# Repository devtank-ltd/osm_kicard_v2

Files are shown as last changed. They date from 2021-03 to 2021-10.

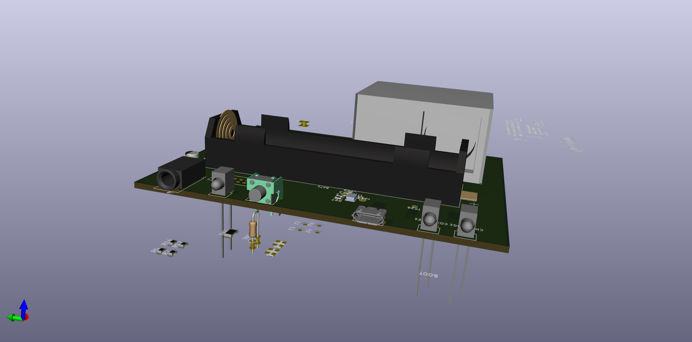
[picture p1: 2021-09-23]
kicad_osm_env01/OSM_env01.png

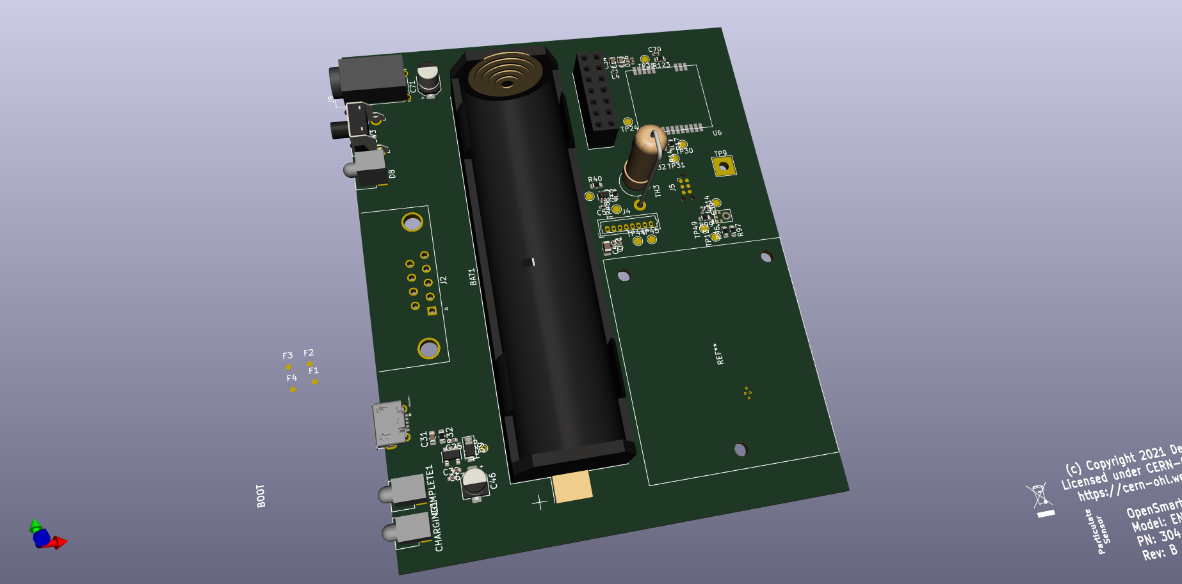
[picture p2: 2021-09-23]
kicad_osm_env01/OSM_env02.png

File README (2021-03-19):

Copyright Devtank Ltd 2021.

This documentation describes Open Hardware and is Licensed under CERN-OHL-W v2.

You may redistribute and modify this documentation under the terms of the CERN-OHL-W v2 (https://cern.ch/cern-ohl). This documentation is distributed WITHOUT ANY EXPRESS OR IMPLIED WARRANTY, INCLUDING OF MERCHANTABILITY, SATISFACTORY QUALITY AND FITNESS FOR A PARTICULAR PURPOSE. Please see the CERN-OHL-W v2 for applicable conditions

Source location: git@github.com:devtank-ltd/kicad_osm_env01.git 

As per CERN-OHL-W v2 section 4.1, should You produce hardware based on these sources, You must maintain the   Source Location visible on the external case of the product you make using this documentation.

This folder contains OSM ENV01 hardware schematics, PCB layout and BOM files. 

You will need Kicad to open hardware design files.

Open Smart Monitor and other test and measurement products can be purchased directly from Devtank Ltd.

Please contact:
Tim Telford
CTO - Devtank Ltd
+44 (0)1332 650944

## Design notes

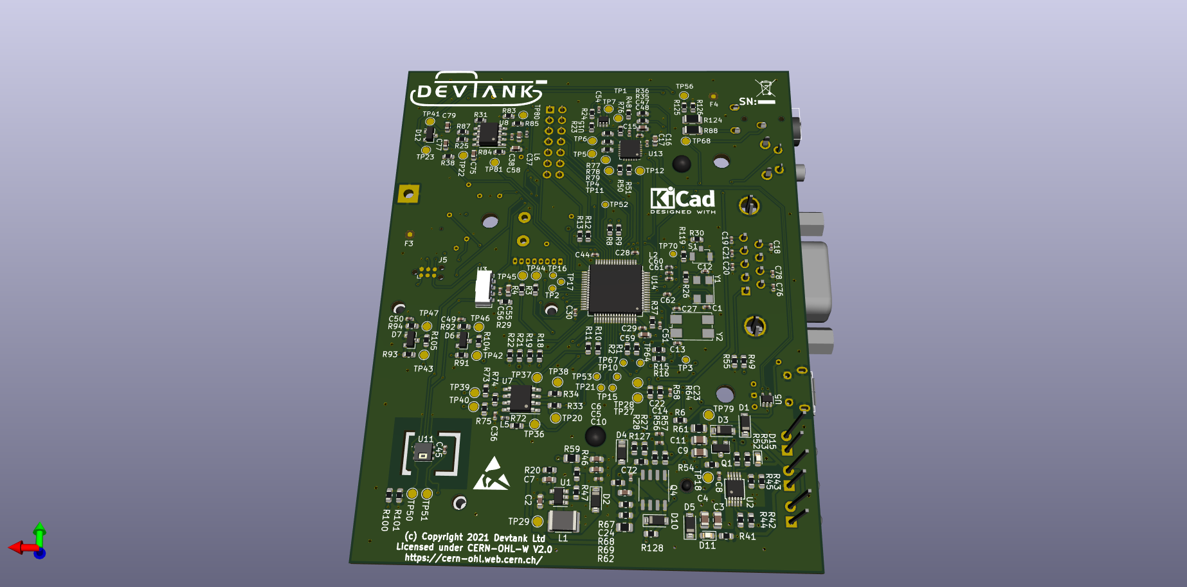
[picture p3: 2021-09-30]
kicad_osm_env01/OSM_env01__revB_img3.png

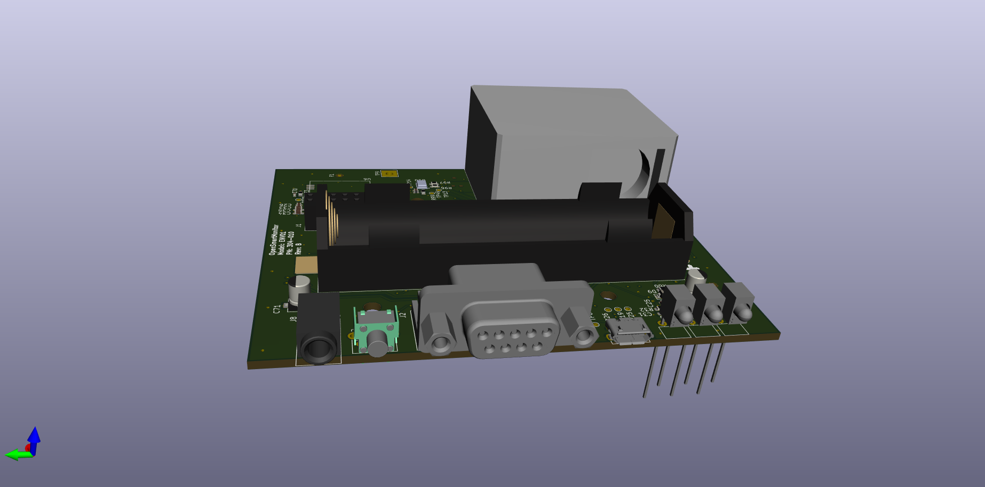
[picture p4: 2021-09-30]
kicad_osm_env01/OSM_env01__revB_img2.png

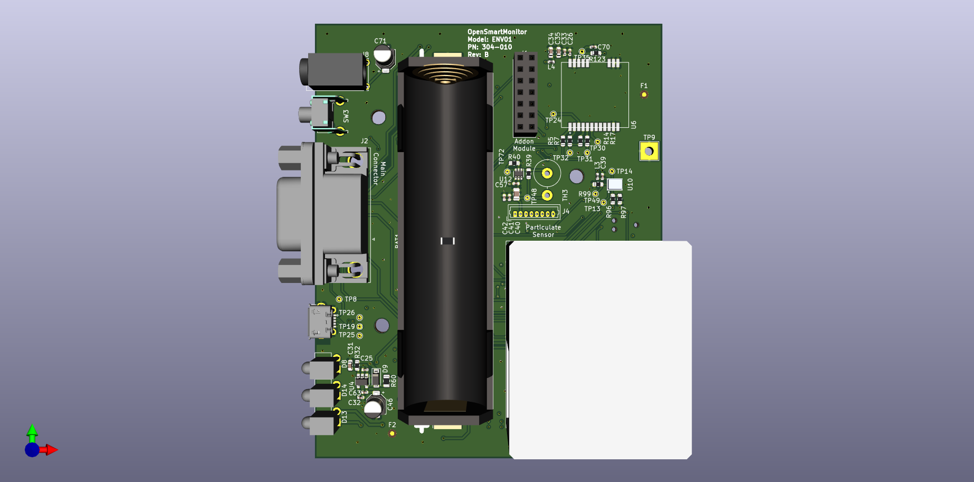
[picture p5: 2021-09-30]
kicad_osm_env01/OSM_env01__revB_img1.png

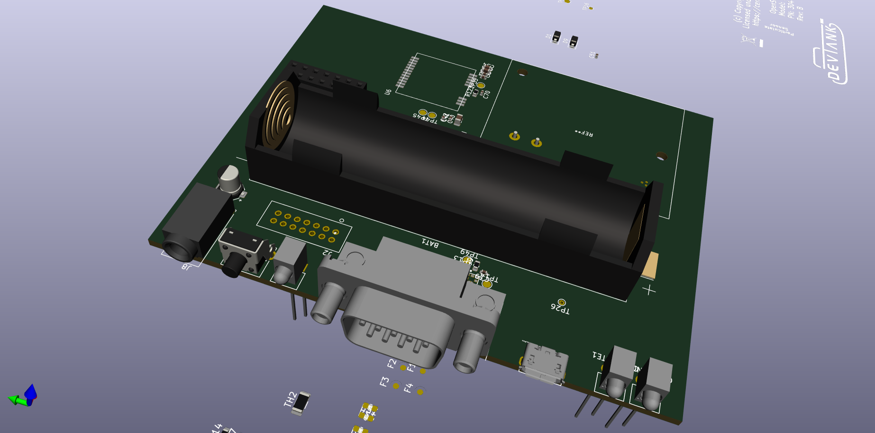
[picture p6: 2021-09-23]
kicad_osm_env01/OSM_env011.png

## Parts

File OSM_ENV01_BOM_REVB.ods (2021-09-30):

Title | Open Smart Monitor |  | Key
Revision | B |  | Orange |  | All resistors to be 1% or better (Can use your own stock)
Date | 2021-09-29 |  | Green |  | All capacitors to be rated minimum 6.3V with the exception of C71 rated 25V (Can use your own stock)
Generated | Wed 29 Sep 2021 14:41:57 BST |  | Purple |  | Use same part or similar L2-L6 to be low esr (Can use your own stock)
Company | Devtank LTD |  | Red |  | Don’t fit part
Comment 1 | Part No: 304-010 |  | Yellow |  | Free issue part by Devtank LTD
Comment 2 |  |  | Black |  | Use exact part
Comment 3
Comment 4
Total Parts | 279
Total Unique Parts | 85
Ref | Qty | Value | Footprint | Voltage | Devtank | Description | Manufacturer | Manufacturer Part Number | Supplier | Supplier Part number | Cost | Total cost | Alternative Manufacturer | Alternative manufacturer part number
BAT1 | 1 | 18650 | Devtank_PCB_lib:BatteryHolder_Keystone_1042_1x18650 |  | 750-002 | Keystone 1042 battery holder for 18650 | Keystone | 1042 | Digikey | 36-1042-ND
C1 C12 | 2 | 10pF | Capacitor_SMD:C_0402_1005Metric
C2 | 1 | 10uF | Capacitor_SMD:C_0603_1608Metric
C3 C4 C9 C11 | 4 | 47uF | Capacitor_SMD:C_0805_2012Metric
C5 C24 C34 C35 C37 | 5 | 10uF | Capacitor_SMD:C_0603_1608Metric
C6 C7 C31 C55 C58 C75 C77 C79 | 8 | DNF | Capacitor_SMD:C_0603_1608Metric
C8 C14 C25 C60 C63 | 5 | 1uF | Capacitor_SMD:C_0402_1005Metric
C10 | 1 | 4.7nF | Capacitor_SMD:C_0402_1005Metric
C13 C27 C32 C72 | 4 | DNF | Capacitor_SMD:C_0402_1005Metric
C15 C17 C22 C23 C26 C28 C29 C30 C33 C36 C38 C39 C41 C44 C45 C48 C51 C54 C56 C57 C62 C70 | 22 | 100nF | Capacitor_SMD:C_0402_1005Metric
C16 C47 C59 | 3 | 4.7uF | Capacitor_SMD:C_0603_1608Metric
C18 C19 C20 C21 C76 C78 | 6 | 100pF | Capacitor_SMD:C_0402_1005Metric
C40 | 1 | 22uF | Capacitor_SMD:C_0805_2012Metric
C42 C49 C50 C61 | 4 | 10nF | Capacitor_SMD:C_0402_1005Metric
C46 | 1 | DNF | Capacitor_SMD:CP_Elec_4x5.4
C71 | 1 | 10uF | Capacitor_SMD:CP_Elec_4x5.4 | 25V | 108-007 | 10uF 25V 5.4mmx4mm | Multicomp Pro | MCVVT025M100CA1L | Farnell | 2611368
D1 D2 D3 D4 D9 | 5 | RB160M-40TR | Diode_SMD:D_SOD-123 |  | 133-016 | Small signal schottkey diode 1A | ROHM | RB160M-40TR | Farnell | 1680023
D5 | 1 | SMFE5-0A | Diode_SMD:D_SOD-123 |  | 136-007 | 5V unidirectional TVS | Eaton | SMFE5-0A | Farnell | 3755203
D6 D7 | 2 | BAV99 | Package_TO_SOT_SMD:SOT-23 |  | 134-001 | BAV99 - Small Signal Diode, Dual Series, 75 V, 300 mA, 1.25 V, 4 ns, 4.5 | Multicomp Pro | BAV99+ | Farnell | 2675152
D8 | 1 | RED | Devtank_PCB_lib:LED_Rectangular_W4.5mm_H7.3mm_Horizontal_2.54mm_Z3.0mm |  | 110-011 | 3mm Circuit board indicator LED orange | Multicomp Pro | L514HAD | Farnell | 2627637
D10 | 1 | DNF | Diode_SMD:D_SOD-123
D11 D15 | 2 | RED | LED_SMD:LED_0603_1608Metric |  | 110-009 | Red LED | ROHM | SML-D12V8WT86C | Digikey | SML-D12V8WT86CCT-ND
D12 | 1 | DNF | Package_TO_SOT_SMD:SOT-23
D13 | 1 | GRN | Devtank_PCB_lib:LED_Rectangular_W4.5mm_H7.3mm_Horizontal_2.54mm_Z3.0mm |  | 110-012 | 3mm Circuit board indicator LED Green | Multicomp Pro | L514HGD | Farnell | 2627638
D14 | 1 | YLW | Devtank_PCB_lib:LED_Rectangular_W4.5mm_H7.3mm_Horizontal_2.54mm_Z3.0mm |  | 110-013 | 3mm Circuit board indicator LED yellow | Multicomp Pro | L514HYD | Farnell | 2627640
F1 F2 F3 F4 | 4 | Fiducial | Fiducial:Fiducial_1mm_Mask2mm
J1 | 1 | DNF | Connector_PinSocket_2.54mm:PinSocket_2x07_P2.54mm_Vertical
J2 | 1 | DB9_Female_MountingHoles | Connector_Dsub:DSUB-9_Female_Horizontal_P2.77x2.84mm_EdgePinOffset7.70mm_Housed_MountingHolesOffset9.12mm |  | 707-009 | 9 Way D Type – Female |  | DMR-09-S | Toby | DMR-09-S |  |  | Multicomp Pro | 5504F1-09S-02A-03
J3 | 1 | USB_B_Micro | Devtank_PCB_lib:MOLEX_105017-0001_USB_B |  | 703-006 | 105017-0001 - USB Connector, Micro USB Type B, USB 2.0, Receptacle, 5 Ways, Surface Mount, Right Angle | Molex | 105017-0001 | Farnell | 2293836
J4 | 1 | Conn_01x08 | Connector_Molex:Molex_PicoBlade_53047-0810_1x08_P1.25mm_Vertical |  | 714-030 | 53047-0810 - Wire-To-Board Connector, Vertical, 1.25 mm, 8 Contacts, Header, PicoBlade 53047 Series | Molex | 53047-0810 | Farnell | 1012258
J5 | 1 | DNF | Connector:Tag-Connect_TC2030-IDC-NL_2x03_P1.27mm_Vertical
J8 | 1 | STX-3000 | Devtank_PCB_lib:STX-3000 |  | 714-036 | STX3000 - Kycon 3.5mm PCB Mount, Low Profile Audio Jack | Kycon | STX-3000 | Toby Electronics | STX-3000
L1 | 1 | 10uH | Inductor_SMD:L_1812_4532Metric |  | 113-005 | LQH43PN100M26L - High Frequency Inductor, 10 µH, LQH43P_26 Series, 1.05 A, 1812 [4532 Metric], Wirewound, 0.147 ohm | muRata | LQH43PN100M26L | Digikey | 490-12780-1-ND
L2 L3 L4 L5 L6 | 5 | 2A/0.05DCR | Inductor_SMD:L_0402_1005Metric |  | 113-006 | Ferrite bead 120R 2A 0.055ohm | TDK | MPZ1005S121HT000 | Farnell | 3288291
Q1 | 1 | SI2301BDS-T1-E3 | Package_TO_SOT_SMD:SOT-23 |  | 173-009 | P-Channel MOSFET, 2.6 A, 20 V, 3-Pin SOT-23 Infineon IRLML2246TRPBF | Infineon | IRLML2246TRPBF | RS | 760-4432
Q4 | 1 | IRF7509TRPBF | Package_SO:SO-8_3.9x4.9mm_P1.27mm |  | 173-010 | Dual MOSFET, Complementary N and P Channel, 30 V, 2.7 A, 0.11 ohm, µSOIC, Surface Mount | Infineon Technologies | IRF7509TRPBF | Digikey | IRF7509TRPBFCT-ND
R1 R2 | 2 | 4.7k | Resistor_SMD:R_0603_1608Metric
R3 R4 R8 R9 R10 R11 R12 R13 R14 R17 R20 R24 R25 R27 R29 R30 R32 R33 R34 R35 R37 R38 R39 R49 R50 R51 R76 R77 R128 | 29 | 0R | Resistor_SMD:R_0603_1608Metric
R5 R7 R15 R23 R28 R31 R36 R55 R92 R94 R96 R100 R101 R119 R127 | 15 | DNF | Resistor_SMD:R_0603_1608Metric
R6 | 1 | 1.3k | Resistor_SMD:R_0603_1608Metric
R16 R48 R56 R72 R91 R93 R123 | 7 | 10k | Resistor_SMD:R_0603_1608Metric
R18 R21 R58 | 3 | 1M | Resistor_SMD:R_0603_1608Metric
R19 R22 R64 R125 R126 | 5 | 470k | Resistor_SMD:R_0603_1608Metric
R26 | 1 | 390R | Resistor_SMD:R_0603_1608Metric
R40 R57 R68 R69 R97 R99 | 6 | 100k | Resistor_SMD:R_0603_1608Metric
R41 R53 | 2 | 2.2k | Resistor_SMD:R_0603_1608Metric
R42 R44 | 2 | 1.6k | Resistor_SMD:R_0603_1608Metric
R43 R45 | 2 | 4.99k | Resistor_SMD:R_0603_1608Metric
R46 | 1 | 110k | Resistor_SMD:R_0603_1608Metric
R47 | 1 | 36k | Resistor_SMD:R_0603_1608Metric
R52 | 1 | 0R | Resistor_SMD:R_0603_1608Metric
R54 | 1 | DNF | Resistor_SMD:R_0603_1608Metric
R59 R60 R61 R62 | 4 | 0R | Resistor_SMD:R_0805_2012Metric
R67 | 1 | 300k | Resistor_SMD:R_0603_1608Metric
R73 R75 | 2 | 470R | Resistor_SMD:R_0603_1608Metric
R74 R87 | 2 | 120R | Resistor_SMD:R_0603_1608Metric
R78 R79 R84 R85 | 4 | 330R | Resistor_SMD:R_0603_1608Metric
R83 | 1 | 680R | Resistor_SMD:R_0603_1608Metric
R88 | 1 | 22R | Resistor_SMD:R_1206_3216Metric
R104 R105 | 2 | 1k | Resistor_SMD:R_0603_1608Metric
R124 | 1 | DNF | Resistor_SMD:R_1206_3216Metric
S1 | 1 | B3U-1100P | Button_Switch_SMD:SW_SPST_B3U-1100P |  | 781-003 | SMD Tactile switch | Omron | B3U-1100P | Digikey
SW3 | 1 | SW_Push | Devtank_PCB_lib:SW_Tactile_SPST_Angled_PTS645Vx58-2LFS |  | 780-002 | PTS645VH58-2LFS - Tactile Switch, PT645 Series, Side Actuated, Through Hole, Round Button, 200 gf, 50mA at 12VDC | C & K Components | PTS645VH58-2LFS | SW1021CT-ND | CKN9120-ND
TH2 | 1 | 10K | Resistor_SMD:R_1206_3216Metric |  | 155-012 | NC20K00103KBA - Thermistor, NTC, 10 kohm, NC20 Series, 3630 K, SMD, 1206 | AVX | NC20K00103KBA | Farnell | 1703890
TH3 | 1 | DNF | Resistor_THT:R_Axial_DIN0617_L17.0mm_D6.0mm_P5.08mm_Vertical
TP1 TP4 TP5 TP6 TP7 TP11 TP12 TP18 TP20 TP22 TP23 TP27 TP28 TP29 TP36 TP37 TP38 TP39 TP40 TP41 TP42 TP43 TP44 TP45 TP46 TP47 TP50 TP51 TP56 TP68 TP79 TP80 TP81 | 33 | Test_Point | TestPoint:TestPoint_Pad_D1.5mm
TP2 TP3 TP10 TP15 TP16 TP17 TP21 TP52 TP53 TP64 TP67 TP70 | 12 | Test_Point | TestPoint:TestPoint_Pad_D1.0mm
TP8 TP13 TP14 TP19 TP24 TP25 TP26 TP30 TP31 TP32 TP35 TP48 TP49 TP72 | 14 | Test_Point | TestPoint:TestPoint_THTPad_D1.0mm_Drill0.5mm
TP9 | 1 | Test_Point | TestPoint:TestPoint_THTPad_4.0x4.0mm_Drill2.0mm
U1 | 1 | MIC2250-1YD5 | Package_TO_SOT_SMD:SOT-23-5 |  | 151-008 | 2.5 MHz 2 A SMT Low EMI Boost Regulator low quiescent current 2.5-5.5v in, Output adjustable | Microchip Technology | MIC2250-1YD5-TR | Mouser | 998-MIC2250-1YD5TR
U2 | 1 | MCP73833 | Package_SO:MSOP-10_3x3mm_P0.5mm |  | 123-015 | FREE ISSUE
U3 | 1 | VEML7700-TT | Devtank_PCB_lib:VEML7700-TT |  | 155-013 | Ambient Light Sensor, VEML7700, Digital, 16 Bit, I2C, 2.5 Vdc to 3.6 Vdc | Vishay | VEML7700-TT | Digikey | 751-VEML7700-TTCT-ND
U4 | 1 | MIC5219-3.3 | Package_TO_SOT_SMD:SOT-23-5 |  | 150-009 | Low quiescent current ldo 2.5-12Vin, fixed 3.3Vout 200-500mA | Microchip Technology | MIC5219-3.3YM5-TR | Digikey | 576-1281-1-ND
U5 | 1 | SP3003-02JTG | Package_TO_SOT_SMD:SOT-353_SC-70-5 |  | 153-004 | Dual Uni-Directional TVS Diode Array | Littlefuse Inc. | SP3003-02JTG | Digikey | F3301CT-ND
U6 | 1 | RAK4270 | Devtank_PCB_lib:RAK4270_WisDuo_LPWAN_Module |  | 118-016 | FREE ISSUE
U7 | 1 | ST3485EBDR | Package_SO:SOIC-8_3.9x4.9mm_P1.27mm |  | 118-017 | Half duplex CAN Transceiver | STMicroelectronics | ST3485EBDR | RS | ST3485EBDR
U8 | 1 | DNF | Package_SO:SOIC-8_3.9x4.9mm_P1.27mm
U10 | 1 | ICS-43434 | Devtank_PCB_lib:ICS-43434 |  | 155-014 | Mic Omni-Directional -26dB 3.63V IC | TDK Invensense | ICS-43434 | Digikey | 1428-1066-1-ND
U11 | 1 | HPP845E131R5 | Devtank_PCB_lib:HPP845E131R5_temperature_humidity_sensor |  | 155-015 | HUMIDITY/TEMP SENSOR HPP845E131R5, -40 TO 125DEG C | TE Connectivity | HPP845E131R5 | RS | 187-9316
U12 | 1 | MIC94073YC6 | Package_TO_SOT_SMD:SOT-363_SC-70-6 |  | 146-002 | MIC94073YC6-TR high side load switch | Microchip Technology | MIC94073YC6-TR | Digikey | 576-3014-1-ND
U13 | 1 | CP2102N-A02-GQFN24 | Devtank_PCB_lib:CP2102_QFN-24-1EP_4x4mm_P0.5mm_EP2.6x2.6mm_ThermalVias_0.3mmdrill |  | 118-007 | FREE ISSUE
U14 | 1 | STM32L451RCTx | Package_QFP:LQFP-64_10x10mm_P0.5mm |  | 126-006 | FREE ISSUE
U15 | 1 | M74VHC1GT14DFT2G | Package_TO_SOT_SMD:SOT-353_SC-70-5 |  | 123-016 | M74VHC1GT14DFT2G Schmitt trigger inverter | On Semi | M74VHC1GT14DFT2G | Digikey | M74VHC1GT14DFT2GOSCT-ND
Y1 | 1 | 8MHZ | Crystal:Crystal_SMD_Abracon_ABM3C-4Pin_5.0x3.2mm |  | 181-013 | 8Mhz Crystal SMD, 5mm x 3.2mm, 30 ppm, 10 pF | Multicomp Pro | MCSJK-7I-8.00-10-30-60-B-30 | Farnell | 2854011
Y2 | 1 | DNF | Crystal:Crystal_SMD_7050-4Pin_7.0x5.0mm
BOM made with KICAD_BOM_WIZARD (https://github.com/HashDefineElectronics/KiCad_BOM_Wizard.git)
Generated Wed 29 Sep 2021 14:41:57 BST

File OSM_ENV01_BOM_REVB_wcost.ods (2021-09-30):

Title | Open Smart Monitor |  | Key
Revision | B |  | Orange |  | All resistors to be 1% or better (Can use your own stock)
Date | 2021-09-29 |  | Green |  | All capacitors to be rated minimum 6.3V with the exception of C71 rated 25V (Can use your own stock)
Generated | Wed 29 Sep 2021 14:41:57 BST |  | Purple |  | Use same part or similar L2-L6 to be low esr (Can use your own stock)
Company | Devtank LTD |  | Red |  | Don’t fit part
Comment 1 | Part No: 304-010 |  | Yellow |  | Free issue part by Devtank LTD
Comment 2 |  |  | Black |  | Use exact part
Comment 3
Comment 4
Total Parts | 279
Total Unique Parts | 85
Ref | Qty | Value | Footprint | Voltage | Devtank | Description | Manufacturer | Manufacturer Part Number | Supplier | Supplier Part number | Cost | Total cost | Alternative Manufacturer | Alternative manufacturer part number
BAT1 | 1 | 18650 | Devtank_PCB_lib:BatteryHolder_Keystone_1042_1x18650 |  | 750-002 | Keystone 1042 battery holder for 18650 | Keystone | 1042 | Digikey | 36-1042-ND | 2.55 | 2.55
C1 C12 | 2 | 10pF | Capacitor_SMD:C_0402_1005Metric |  |  |  |  |  |  |  |  | 0
C2 | 1 | 10uF | Capacitor_SMD:C_0603_1608Metric |  |  |  |  |  |  |  |  | 0
C3 C4 C9 C11 | 4 | 47uF | Capacitor_SMD:C_0805_2012Metric |  |  |  |  |  |  |  |  | 0
C5 C24 C34 C35 C37 | 5 | 10uF | Capacitor_SMD:C_0603_1608Metric |  |  |  |  |  |  |  |  | 0
C6 C7 C31 C55 C58 C75 C77 C79 | 8 | DNF | Capacitor_SMD:C_0603_1608Metric |  |  |  |  |  |  |  |  | 0
C8 C14 C25 C60 C63 | 5 | 1uF | Capacitor_SMD:C_0402_1005Metric |  |  |  |  |  |  |  |  | 0
C10 | 1 | 4.7nF | Capacitor_SMD:C_0402_1005Metric |  |  |  |  |  |  |  |  | 0
C13 C27 C32 C72 | 4 | DNF | Capacitor_SMD:C_0402_1005Metric |  |  |  |  |  |  |  |  | 0
C15 C17 C22 C23 C26 C28 C29 C30 C33 C36 C38 C39 C41 C44 C45 C48 C51 C54 C56 C57 C62 C70 | 22 | 100nF | Capacitor_SMD:C_0402_1005Metric |  |  |  |  |  |  |  |  | 0
C16 C47 C59 | 3 | 4.7uF | Capacitor_SMD:C_0603_1608Metric |  |  |  |  |  |  |  |  | 0
C18 C19 C20 C21 C76 C78 | 6 | 100pF | Capacitor_SMD:C_0402_1005Metric |  |  |  |  |  |  |  |  | 0
C40 | 1 | 22uF | Capacitor_SMD:C_0805_2012Metric |  |  |  |  |  |  |  |  | 0
C42 C49 C50 C61 | 4 | 10nF | Capacitor_SMD:C_0402_1005Metric |  |  |  |  |  |  |  |  | 0
C46 | 1 | DNF | Capacitor_SMD:CP_Elec_4x5.4 |  |  |  |  |  |  |  |  | 0
C71 | 1 | 10uF | Capacitor_SMD:CP_Elec_4x5.4 | 25V | 108-007 | 10uF 25V 5.4mmx4mm | Multicomp Pro | MCVVT025M100CA1L | Farnell | 2611368 | 0.0562 | 0.0562
D1 D2 D3 D4 D9 | 5 | RB160M-40TR | Diode_SMD:D_SOD-123 |  | 133-016 | Small signal schottkey diode 1A | ROHM | RB160M-40TR | Farnell | 1680023 | 0.279 | 1.395
D5 | 1 | SMFE5-0A | Diode_SMD:D_SOD-123 |  | 136-007 | 5V unidirectional TVS | Eaton | SMFE5-0A | Farnell | 3755203 | 0.141 | 0.141
D6 D7 | 2 | BAV99 | Package_TO_SOT_SMD:SOT-23 |  | 134-001 | BAV99 - Small Signal Diode, Dual Series, 75 V, 300 mA, 1.25 V, 4 ns, 4.5 | Multicomp Pro | BAV99+ | Farnell | 2675152 | 0.0581 | 0.1162
D8 | 1 | RED | Devtank_PCB_lib:LED_Rectangular_W4.5mm_H7.3mm_Horizontal_2.54mm_Z3.0mm |  | 110-011 | 3mm Circuit board indicator LED orange | Multicomp Pro | L514HAD | Farnell | 2627637 | 0.261 | 0.261
D10 | 1 | DNF | Diode_SMD:D_SOD-123 |  |  |  |  |  |  |  |  | 0
D11 D15 | 2 | RED | LED_SMD:LED_0603_1608Metric |  | 110-009 | Red LED | ROHM | SML-D12V8WT86C | Digikey | SML-D12V8WT86CCT-ND | 0.16 | 0.32
D12 | 1 | DNF | Package_TO_SOT_SMD:SOT-23 |  |  |  |  |  |  |  |  | 0
D13 | 1 | GRN | Devtank_PCB_lib:LED_Rectangular_W4.5mm_H7.3mm_Horizontal_2.54mm_Z3.0mm |  | 110-012 | 3mm Circuit board indicator LED Green | Multicomp Pro | L514HGD | Farnell | 2627638 | 0.261 | 0.261
D14 | 1 | YLW | Devtank_PCB_lib:LED_Rectangular_W4.5mm_H7.3mm_Horizontal_2.54mm_Z3.0mm |  | 110-013 | 3mm Circuit board indicator LED yellow | Multicomp Pro | L514HYD | Farnell | 2627640 | 0.261 | 0.261
F1 F2 F3 F4 | 4 | Fiducial | Fiducial:Fiducial_1mm_Mask2mm |  |  |  |  |  |  |  |  | 0
J1 | 1 | DNF | Connector_PinSocket_2.54mm:PinSocket_2x07_P2.54mm_Vertical |  |  |  |  |  |  |  |  | 0
J2 | 1 | DB9_Female_MountingHoles | Connector_Dsub:DSUB-9_Female_Horizontal_P2.77x2.84mm_EdgePinOffset7.70mm_Housed_MountingHolesOffset9.12mm |  | 707-009 | 9 Way D Type – Female | Valcon | DMR-09-S | Toby | DMR-09-S | 0.311 | 0.311 | Multicomp Pro | 5504F1-09S-02A-03
J3 | 1 | USB_B_Micro | Devtank_PCB_lib:MOLEX_105017-0001_USB_B |  | 703-006 | 105017-0001 - USB Connector, Micro USB Type B, USB 2.0, Receptacle, 5 Ways, Surface Mount, Right Angle | Molex | 105017-0001 | Farnell | 2293836 | 0.544 | 0.544
J4 | 1 | Conn_01x08 | Connector_Molex:Molex_PicoBlade_53047-0810_1x08_P1.25mm_Vertical |  | 714-030 | 53047-0810 - Wire-To-Board Connector, Vertical, 1.25 mm, 8 Contacts, Header, PicoBlade 53047 Series | Molex | 53047-0810 | Farnell | 1012258 | 0.267 | 0.267
J5 | 1 | DNF | Connector:Tag-Connect_TC2030-IDC-NL_2x03_P1.27mm_Vertical |  |  |  |  |  |  |  |  | 0
J8 | 1 | STX-3000 | Devtank_PCB_lib:STX-3000 |  | 714-036 | STX3000 - Kycon 3.5mm PCB Mount, Low Profile Audio Jack | Kycon | STX-3000 | Toby Electronics | STX-3000 | 0.38 | 0.38
L1 | 1 | 10uH | Inductor_SMD:L_1812_4532Metric |  | 113-005 | LQH43PN100M26L - High Frequency Inductor, 10 µH, LQH43P_26 Series, 1.05 A, 1812 [4532 Metric], Wirewound, 0.147 ohm | muRata | LQH43PN100M26L | Digikey | 490-12780-1-ND | 0.19 | 0.19
L2 L3 L4 L5 L6 | 5 | 2A/0.05DCR | Inductor_SMD:L_0402_1005Metric |  | 113-006 | Ferrite bead 120R 2A 0.055ohm | TDK | MPZ1005S121HT000 | Farnell | 3288291 | 0.0694 | 0.347
Q1 | 1 | SI2301BDS-T1-E3 | Package_TO_SOT_SMD:SOT-23 |  | 173-009 | P-Channel MOSFET, 2.6 A, 20 V, 3-Pin SOT-23 Infineon IRLML2246TRPBF | Infineon | IRLML2246TRPBF | RS | 760-4432 | 0.344 | 0.344
Q4 | 1 | IRF7509TRPBF | Package_SO:SO-8_3.9x4.9mm_P1.27mm |  | 173-010 | Dual MOSFET, Complementary N and P Channel, 30 V, 2.7 A, 0.11 ohm, µSOIC, Surface Mount | Infineon Technologies | IRF7509TRPBF | Digikey | IRF7509TRPBFCT-ND | 0.552 | 0.552
R1 R2 | 2 | 4.7k | Resistor_SMD:R_0603_1608Metric |  |  |  |  |  |  |  |  | 0
R3 R4 R8 R9 R10 R11 R12 R13 R14 R17 R20 R24 R25 R27 R29 R30 R32 R33 R34 R35 R37 R38 R39 R49 R50 R51 R76 R77 R128 | 29 | 0R | Resistor_SMD:R_0603_1608Metric |  |  |  |  |  |  |  |  | 0
R5 R7 R15 R23 R28 R31 R36 R55 R92 R94 R96 R100 R101 R119 R127 | 15 | DNF | Resistor_SMD:R_0603_1608Metric |  |  |  |  |  |  |  |  | 0
R6 | 1 | 1.3k | Resistor_SMD:R_0603_1608Metric |  |  |  |  |  |  |  |  | 0
R16 R48 R56 R72 R91 R93 R123 | 7 | 10k | Resistor_SMD:R_0603_1608Metric |  |  |  |  |  |  |  |  | 0
R18 R21 R58 | 3 | 1M | Resistor_SMD:R_0603_1608Metric |  |  |  |  |  |  |  |  | 0
R19 R22 R64 R125 R126 | 5 | 470k | Resistor_SMD:R_0603_1608Metric |  |  |  |  |  |  |  |  | 0
R26 | 1 | 390R | Resistor_SMD:R_0603_1608Metric |  |  |  |  |  |  |  |  | 0
R40 R57 R68 R69 R97 R99 | 6 | 100k | Resistor_SMD:R_0603_1608Metric |  |  |  |  |  |  |  |  | 0
R41 R53 | 2 | 2.2k | Resistor_SMD:R_0603_1608Metric |  |  |  |  |  |  |  |  | 0
R42 R44 | 2 | 1.6k | Resistor_SMD:R_0603_1608Metric |  |  |  |  |  |  |  |  | 0
R43 R45 | 2 | 4.99k | Resistor_SMD:R_0603_1608Metric |  |  |  |  |  |  |  |  | 0
R46 | 1 | 110k | Resistor_SMD:R_0603_1608Metric |  |  |  |  |  |  |  |  | 0
R47 | 1 | 36k | Resistor_SMD:R_0603_1608Metric |  |  |  |  |  |  |  |  | 0
R52 | 1 | 0R | Resistor_SMD:R_0603_1608Metric |  |  |  |  |  |  |  |  | 0
R54 | 1 | DNF | Resistor_SMD:R_0603_1608Metric |  |  |  |  |  |  |  |  | 0
R59 R60 R61 R62 | 4 | 0R | Resistor_SMD:R_0805_2012Metric |  |  |  |  |  |  |  |  | 0
R67 | 1 | 300k | Resistor_SMD:R_0603_1608Metric |  |  |  |  |  |  |  |  | 0
R73 R75 | 2 | 470R | Resistor_SMD:R_0603_1608Metric |  |  |  |  |  |  |  |  | 0
R74 R87 | 2 | 120R | Resistor_SMD:R_0603_1608Metric |  |  |  |  |  |  |  |  | 0
R78 R79 R84 R85 | 4 | 330R | Resistor_SMD:R_0603_1608Metric |  |  |  |  |  |  |  |  | 0
R83 | 1 | 680R | Resistor_SMD:R_0603_1608Metric |  |  |  |  |  |  |  |  | 0
R88 | 1 | 22R | Resistor_SMD:R_1206_3216Metric |  |  |  |  |  |  |  |  | 0
R104 R105 | 2 | 1k | Resistor_SMD:R_0603_1608Metric |  |  |  |  |  |  |  |  | 0
R124 | 1 | DNF | Resistor_SMD:R_1206_3216Metric |  |  |  |  |  |  |  |  | 0
S1 | 1 | B3U-1100P | Button_Switch_SMD:SW_SPST_B3U-1100P |  | 781-003 | SMD Tactile switch SPST-NO 50mA 12V | Omron | B3U-1100P | Digikey |  | 0.63 | 0.63
SW3 | 1 | SW_Push | Devtank_PCB_lib:SW_Tactile_SPST_Angled_PTS645Vx58-2LFS |  | 780-002 | PTS645VH58-2LFS - Tactile Switch, PT645 Series, Side Actuated, Through Hole, Round Button, 200 gf, 50mA at 12VDC | C & K Components | PTS645VH58-2LFS | SW1021CT-ND | CKN9120-ND | 0.18 | 0.18
TH2 | 1 | 10K | Resistor_SMD:R_1206_3216Metric |  | 155-012 | NC20K00103KBA - Thermistor, NTC, 10 kohm, NC20 Series, 3630 K, SMD, 1206 | AVX | NC20K00103KBA | Farnell | 1703890 | 0.311 | 0.311
TH3 | 1 | DNF | Resistor_THT:R_Axial_DIN0617_L17.0mm_D6.0mm_P5.08mm_Vertical |  |  |  |  |  |  |  |  | 0
TP1 TP4 TP5 TP6 TP7 TP11 TP12 TP18 TP20 TP22 TP23 TP27 TP28 TP29 TP36 TP37 TP38 TP39 TP40 TP41 TP42 TP43 TP44 TP45 TP46 TP47 TP50 TP51 TP56 TP68 TP79 TP80 TP81 | 33 | Test_Point | TestPoint:TestPoint_Pad_D1.5mm |  |  |  |  |  |  |  |  | 0
TP2 TP3 TP10 TP15 TP16 TP17 TP21 TP52 TP53 TP64 TP67 TP70 | 12 | Test_Point | TestPoint:TestPoint_Pad_D1.0mm |  |  |  |  |  |  |  |  | 0
TP8 TP13 TP14 TP19 TP24 TP25 TP26 TP30 TP31 TP32 TP35 TP48 TP49 TP72 | 14 | Test_Point | TestPoint:TestPoint_THTPad_D1.0mm_Drill0.5mm |  |  |  |  |  |  |  |  | 0
TP9 | 1 | Test_Point | TestPoint:TestPoint_THTPad_4.0x4.0mm_Drill2.0mm |  |  |  |  |  |  |  |  | 0
U1 | 1 | MIC2250-1YD5 | Package_TO_SOT_SMD:SOT-23-5 |  | 151-008 | 2.5 MHz 2 A SMT Low EMI Boost Regulator low quiescent current 2.5-5.5v in, Output adjustable | Microchip Technology | MIC2250-1YD5-TR | Mouser | 998-MIC2250-1YD5TR | 0.526 | 0.526
U2 | 1 | MCP73833 | Package_SO:MSOP-10_3x3mm_P0.5mm |  | 123-015 | Stand-Alone Linear Battery Charge Controller | Microchip Technology | MCP73833T-AMI/UN | Digikey998-MIC2250-1YD5TR | MCP73833T-AMI/UNCT-ND | 0.64 | 0.64
U3 | 1 | VEML7700-TT | Devtank_PCB_lib:VEML7700-TT |  | 155-013 | Ambient Light Sensor, VEML7700, Digital, 16 Bit, I2C, 2.5 Vdc to 3.6 Vdc | Vishay | VEML7700-TT | Digikey | 751-VEML7700-TTCT-ND | 0.9 | 0.9
U4 | 1 | MIC5219-3.3 | Package_TO_SOT_SMD:SOT-23-5 |  | 150-009 | Low quiescent current ldo 2.5-12Vin, fixed 3.3Vout 200mA, 500mA peak current | Microchip Technology | MIC5219-3.3YM5-TR | Digikey | 576-1281-1-ND | 0.664 | 0.664
U5 | 1 | SP3003-02JTG | Package_TO_SOT_SMD:SOT-353_SC-70-5 |  | 153-004 | Dual Uni-Directional TVS Diode Array | Littlefuse Inc. | SP3003-02JTG | Digikey | F3301CT-ND | 0.615 | 0.615
U6 | 1 | RAK4270 | Devtank_PCB_lib:RAK4270_WisDuo_LPWAN_Module |  | 118-016 | RAK4270 WisDuo LPWAN Module with IPEX EU868 | rakwireless | RAK4270 WisDuo LPWAN Module with IPEX EU868 | rakwireless | RAK4270 WisDuo LPWAN Module with IPEX EU868 | 5.2 | 5.2
U7 | 1 | ST3485EBDR | Package_SO:SOIC-8_3.9x4.9mm_P1.27mm |  | 118-017 | Half duplex CAN Transceiver | STMicroelectronics | ST3485EBDR | RS | ST3485EBDR | 1.72 | 1.72
U8 | 1 | DNF | Package_SO:SOIC-8_3.9x4.9mm_P1.27mm |  |  |  |  |  |  |  |  | 0
U10 | 1 | ICS-43434 | Devtank_PCB_lib:ICS-43434 |  | 155-014 | Mic Omni-Directional -26dB 3.63V IC | TDK Invensense | ICS-43434 | Digikey | 1428-1066-1-ND | 1.369 | 1.369
U11 | 1 | HPP845E131R5 | Devtank_PCB_lib:HPP845E131R5_temperature_humidity_sensor |  | 155-015 | HUMIDITY/TEMP SENSOR HPP845E131R5, -40 TO 125DEG C | TE Connectivity | HPP845E131R5 | RS | 187-9316 | 1.534 | 1.534
U12 | 1 | MIC94073YC6 | Package_TO_SOT_SMD:SOT-363_SC-70-6 |  | 146-002 | MIC94073YC6-TR high side load switch | Microchip Technology | MIC94073YC6-TR | Digikey | 576-3014-1-ND | 0.339 | 0.339
U13 | 1 | CP2102N-A02-GQFN24 | Devtank_PCB_lib:CP2102_QFN-24-1EP_4x4mm_P0.5mm_EP2.6x2.6mm_ThermalVias_0.3mmdrill |  | 118-007 | Silicon Labs CP2102N-A02-GQFN24, USB Controller, 12Mbps, USB 2.0, 3 to 3.6 V, 24-Pin QFN | Silicon Labs | CP2102N-A02-GQFN24 | Mouser | 634-CP2102NA02GQFN24 | 1.46 | 1.46
U14 | 1 | STM32L451RCTx | Package_QFP:LQFP-64_10x10mm_P0.5mm |  | 126-006 | STM32L451RCT6 Microcontroler | STMicroelectronics | STM32L451RCT6 | Digikey | 497-17975-ND | 4.489 | 4.489
U15 | 1 | M74VHC1GT14DFT2G | Package_TO_SOT_SMD:SOT-353_SC-70-5 |  | 123-016 | M74VHC1GT14DFT2G Schmitt trigger inverter | On Semi | M74VHC1GT14DFT2G | Digikey | M74VHC1GT14DFT2GOSCT-ND | 0.138 | 0.138
Y1 | 1 | 8MHZ | Crystal:Crystal_SMD_Abracon_ABM3C-4Pin_5.0x3.2mm |  | 181-013 | 8Mhz Crystal SMD, 5mm x 3.2mm, 30 ppm, 10 pF | Multicomp Pro | MCSJK-7I-8.00-10-30-60-B-30 | Farnell | 2854011 | 0.286 | 0.286
Y2 | 1 | DNF | Crystal:Crystal_SMD_7050-4Pin_7.0x5.0mm |  |  |  |  |  |  |  |  | 0
 |  |  |  |  |  |  |  |  |  |  |  | 29.2974
BOM made with KICAD_BOM_WIZARD (https://github.com/HashDefineElectronics/KiCad_BOM_Wizard.git)
Generated Wed 29 Sep 2021 14:41:57 BST

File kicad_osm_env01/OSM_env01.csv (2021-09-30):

Title | Open Smart Monitor
Revision | B
Date | 2021-09-29
Generated | Wed 29 Sep 2021 14:41:57 BST
Company | Devtank LTD
Comment 1 | Part No: 304-010
Comment 2
Comment 3
Comment 4
Total Parts | 279
Total Unique Parts | 85
Ref | Qty | Value | Footprint | Datasheet | Current | Devtank | Field4 | Field5 | Field6 | Field7 | Field8 | Fieldname 1 | Fieldname2 | Fieldname3 | MANUFACTURER | Package | Voltage
BAT1 | 1 | 18650 | Devtank_PCB_lib:BatteryHolder_Keystone_1042_1x18650 |  |  |  |  |  |  |  |  | Value 1 | Value2 | Value3
C1 C12 | 2 | 18pF | Capacitor_SMD:C_0402_1005Metric
C2 | 1 | 10uF | Capacitor_SMD:C_0603_1608Metric |  |  |  |  |  |  |  |  |  |  |  |  |  | 10V
C3 C4 C9 C11 | 4 | 47uF | Capacitor_SMD:C_0805_2012Metric |  |  |  |  |  |  |  |  |  |  |  |  | 0805
C5 C24 C34 C35 C37 | 5 | 10uF | Capacitor_SMD:C_0603_1608Metric
C6 C7 C31 C55 C58 C75 C77 C79 | 8 | DNF | Capacitor_SMD:C_0603_1608Metric
C8 C14 C25 C60 C63 | 5 | 1uF | Capacitor_SMD:C_0402_1005Metric
C10 | 1 | 4.7nF | Capacitor_SMD:C_0402_1005Metric
C13 C27 C32 C72 | 4 | DNF | Capacitor_SMD:C_0402_1005Metric
C15 C17 C22 C23 C26 C28 C29 C30 C33 C36 C38 C39 C41 C44 C45 C48 C51 C54 C56 C57 C62 C70 | 22 | 100nF | Capacitor_SMD:C_0402_1005Metric
C16 C47 C59 | 3 | 4.7uF | Capacitor_SMD:C_0603_1608Metric
C18 C19 C20 C21 C76 C78 | 6 | 100pF | Capacitor_SMD:C_0402_1005Metric
C40 | 1 | 22uF | Capacitor_SMD:C_0805_2012Metric
C42 C49 C50 C61 | 4 | 10nF | Capacitor_SMD:C_0402_1005Metric
C46 | 1 | DNF | Capacitor_SMD:CP_Elec_4x5.4
C71 | 1 | 10uF | Capacitor_SMD:CP_Elec_4x5.4
D1 D2 D3 D4 D9 | 5 | RB160M-40TR | Diode_SMD:D_SOD-123
D5 | 1 | SMFE5-0A | Diode_SMD:D_SOD-123 | https://en.wikipedia.org/wiki/Transient-voltage-suppression_diode
D6 D7 | 2 | BAV99 | Package_TO_SOT_SMD:SOT-23 | www.nxp.com/documents/data_sheet/BAV99_SER.pdf |  | 134-001
D8 | 1 | RED | Devtank_PCB_lib:LED_Rectangular_W4.5mm_H7.3mm_Horizontal_2.54mm_Z3.0mm | ~
D10 | 1 | DNF | Diode_SMD:D_SOD-123
D11 D15 | 2 | RED | LED_SMD:LED_0603_1608Metric |  |  |  |  |  |  |  |  | Value 1 | Value2 | Value3
D12 | 1 | ESDCAN04-2BLY | Package_TO_SOT_SMD:SOT-23 | https://en.wikipedia.org/wiki/Transient-voltage-suppression_diode
D13 | 1 | GRN | Devtank_PCB_lib:LED_Rectangular_W4.5mm_H7.3mm_Horizontal_2.54mm_Z3.0mm |  |  |  |  |  |  |  |  | Value 1 | Value2 | Value3
D14 | 1 | YLW | Devtank_PCB_lib:LED_Rectangular_W4.5mm_H7.3mm_Horizontal_2.54mm_Z3.0mm |  |  |  |  |  |  |  |  | Value 1 | Value2 | Value3
F1 F2 F3 F4 | 4 | Fiducial | Fiducial:Fiducial_1mm_Mask2mm
J1 | 1 | Conn_02x07_Counter_Clockwise | Connector_PinSocket_2.54mm:PinSocket_2x07_P2.54mm_Vertical | ~
J2 | 1 | DB9_Female_MountingHoles | Connector_Dsub:DSUB-9_Female_Horizontal_P2.77x2.84mm_EdgePinOffset7.70mm_Housed_MountingHolesOffset9.12mm
J3 | 1 | USB_B_Micro | Devtank_PCB_lib:MOLEX_105017-0001_USB_B | ~
J4 | 1 | Conn_01x08 | Connector_Molex:Molex_PicoBlade_53047-0810_1x08_P1.25mm_Vertical | ~
J5 | 1 | Conn_02x03_Odd_Even | Connector:Tag-Connect_TC2030-IDC-NL_2x03_P1.27mm_Vertical | ~
J8 | 1 | STX-3000 | Devtank_PCB_lib:STX-3000
L1 | 1 | 10uH | Inductor_SMD:L_1812_4532Metric |  | 1A
L2 L3 L4 L5 L6 | 5 | 2A/0.05DCR | Inductor_SMD:L_0402_1005Metric
Q1 | 1 | SI2301BDS-T1-E3 | Package_TO_SOT_SMD:SOT-23 | https://www.fairchildsemi.com/datasheets/BS/BSS138.pdf
Q4 | 1 | IRF7509TRPBF | Package_SO:SO-8_3.9x4.9mm_P1.27mm | Mosfet Array N and P-Channel 30V 2W Surface Mount 8-SO |  |  | Infineon Technologies | Unavailable | SO-8 Infineon | None | IRF7319TRPBF
R1 R2 | 2 | 4.7k | Resistor_SMD:R_0603_1608Metric
R3 R4 R8 R9 R10 R11 R12 R13 R14 R17 R20 R24 R25 R27 R29 R30 R32 R33 R34 R35 R37 R38 R39 R49 R50 R51 R76 R77 R128 | 29 | 0R | Resistor_SMD:R_0603_1608Metric
R5 R7 R15 R23 R28 R31 R36 R55 R92 R94 R96 R100 R101 R119 R127 | 15 | DNF | Resistor_SMD:R_0603_1608Metric
R6 | 1 | 1.3k | Resistor_SMD:R_0603_1608Metric
R16 R48 R56 R72 R91 R93 R123 | 7 | 10k | Resistor_SMD:R_0603_1608Metric
R18 R21 R58 | 3 | 1M | Resistor_SMD:R_0603_1608Metric
R19 R22 R64 R125 R126 | 5 | 470k | Resistor_SMD:R_0603_1608Metric
R26 | 1 | 390R | Resistor_SMD:R_0603_1608Metric
R40 R57 R68 R69 R97 R99 | 6 | 100k | Resistor_SMD:R_0603_1608Metric
R41 R53 | 2 | 2.2k | Resistor_SMD:R_0603_1608Metric |  |  |  |  |  |  |  |  | Value 1 | Value2 | Value3
R42 R44 | 2 | 1.6k | Resistor_SMD:R_0603_1608Metric |  |  |  |  |  |  |  |  | Value 1 | Value2 | Value3
R43 R45 | 2 | 4.99k | Resistor_SMD:R_0603_1608Metric |  |  |  |  |  |  |  |  | Value 1 | Value2 | Value3
R46 | 1 | 110k | Resistor_SMD:R_0603_1608Metric
R47 | 1 | 36k | Resistor_SMD:R_0603_1608Metric
R52 | 1 | 0R | Resistor_SMD:R_0603_1608Metric |  |  |  |  |  |  |  |  | Value 1 | Value2 | Value3
R54 | 1 | DNF | Resistor_SMD:R_0603_1608Metric |  |  |  |  |  |  |  |  | Value 1 | Value2 | Value3
R59 R60 R61 R62 | 4 | 0R | Resistor_SMD:R_0805_2012Metric
R67 | 1 | 300k | Resistor_SMD:R_0603_1608Metric
R73 R75 | 2 | 470R | Resistor_SMD:R_0603_1608Metric
R74 R87 | 2 | 120R | Resistor_SMD:R_0603_1608Metric
R78 R79 R84 R85 | 4 | 330R | Resistor_SMD:R_0603_1608Metric
R83 | 1 | 680R | Resistor_SMD:R_0603_1608Metric
R88 | 1 | 22R | Resistor_SMD:R_1206_3216Metric
R104 R105 | 2 | 1k | Resistor_SMD:R_0603_1608Metric
R124 | 1 | DNF | Resistor_SMD:R_1206_3216Metric
S1 | 1 | B3U-1100P | Button_Switch_SMD:SW_SPST_B3U-1100P |  |  |  |  |  |  |  |  |  |  |  | Omron
SW3 | 1 | SW_Push | Devtank_PCB_lib:SW_Tactile_SPST_Angled_PTS645Vx58-2LFS
TH2 | 1 | 10K | Resistor_SMD:R_1206_3216Metric
TH3 | 1 | DNF | Resistor_THT:R_Axial_DIN0617_L17.0mm_D6.0mm_P5.08mm_Vertical
TP1 TP4 TP5 TP6 TP7 TP11 TP12 TP18 TP20 TP22 TP23 TP27 TP28 TP29 TP36 TP37 TP38 TP39 TP40 TP41 TP42 TP43 TP44 TP45 TP46 TP47 TP50 TP51 TP56 TP68 TP79 TP80 TP81 | 33 | Test_Point | TestPoint:TestPoint_Pad_D1.5mm | ~
TP2 TP3 TP10 TP15 TP16 TP17 TP21 TP52 TP53 TP64 TP67 TP70 | 12 | Test_Point | TestPoint:TestPoint_Pad_D1.0mm | ~
TP8 TP13 TP14 TP19 TP24 TP25 TP26 TP30 TP31 TP32 TP35 TP48 TP49 TP72 | 14 | Test_Point | TestPoint:TestPoint_THTPad_D1.0mm_Drill0.5mm | ~
TP9 | 1 | Test_Point | TestPoint:TestPoint_THTPad_4.0x4.0mm_Drill2.0mm | ~
U1 | 1 | MIC2250-1YD5 | Package_TO_SOT_SMD:SOT-23-5 | http://ww1.microchip.com/downloads/en/DeviceDoc/mic2177.pdf
U2 | 1 | MCP73833 | Package_SO:MSOP-10_3x3mm_P0.5mm |  |  |  |  |  |  |  |  | Value 1 | Value2 | Value3
U3 | 1 | VEML7700-TT | Devtank_PCB_lib:VEML7700-TT
U4 | 1 | MIC5219-3.3 | Package_TO_SOT_SMD:SOT-23-5 | http://ww1.microchip.com/downloads/en/devicedoc/mic5219.pdf
U5 | 1 | SP3003-02JTG | Package_TO_SOT_SMD:SOT-353_SC-70-5 | DOCUMENTATION
U6 | 1 | RAK4270 | Devtank_PCB_lib:RAK4270_WisDuo_LPWAN_Module
U7 | 1 | ST3485EBDR | Package_SO:SOIC-8_3.9x4.9mm_P1.27mm | http://www.intersil.com/content/dam/Intersil/documents/isl8/isl83483-85-88-90-91.pdf
U8 | 1 | SN65HVD230 | Package_SO:SOIC-8_3.9x4.9mm_P1.27mm | http://www.ti.com/lit/ds/symlink/sn65hvd230.pdf
U10 | 1 | ICS-43434 | Devtank_PCB_lib:ICS-43434
U11 | 1 | HPP845E131R5 | Devtank_PCB_lib:HPP845E131R5_temperature_humidity_sensor
U12 | 1 | MIC94073YC6 | Package_TO_SOT_SMD:SOT-363_SC-70-6
U13 | 1 | CP2102N-A01-GQFN24 | Devtank_PCB_lib:CP2102_QFN-24-1EP_4x4mm_P0.5mm_EP2.6x2.6mm_ThermalVias_0.3mmdrill | http://www.silabs.com/support%20documents/technicaldocs/cp2102n-datasheet.pdf |  | 118-007
U14 | 1 | STM32L451RCTx | Package_QFP:LQFP-64_10x10mm_P0.5mm | http://www.st.com/st-web-ui/static/active/en/resource/technical/document/datasheet/DM00108832.pdf
U15 | 1 | M74VHC1GT14DFT2G | Package_TO_SOT_SMD:SOT-353_SC-70-5
Y1 | 1 | 8MHZ | Crystal:Crystal_SMD_Abracon_ABM3C-4Pin_5.0x3.2mm
Y2 | 1 | DNF | Crystal:Crystal_SMD_7050-4Pin_7.0x5.0mm
BOM made with KICAD_BOM_WIZARD (https://github.com/HashDefineElectronics/KiCad_BOM_Wizard.git)
Generated Wed 29 Sep 2021 14:41:57 BST

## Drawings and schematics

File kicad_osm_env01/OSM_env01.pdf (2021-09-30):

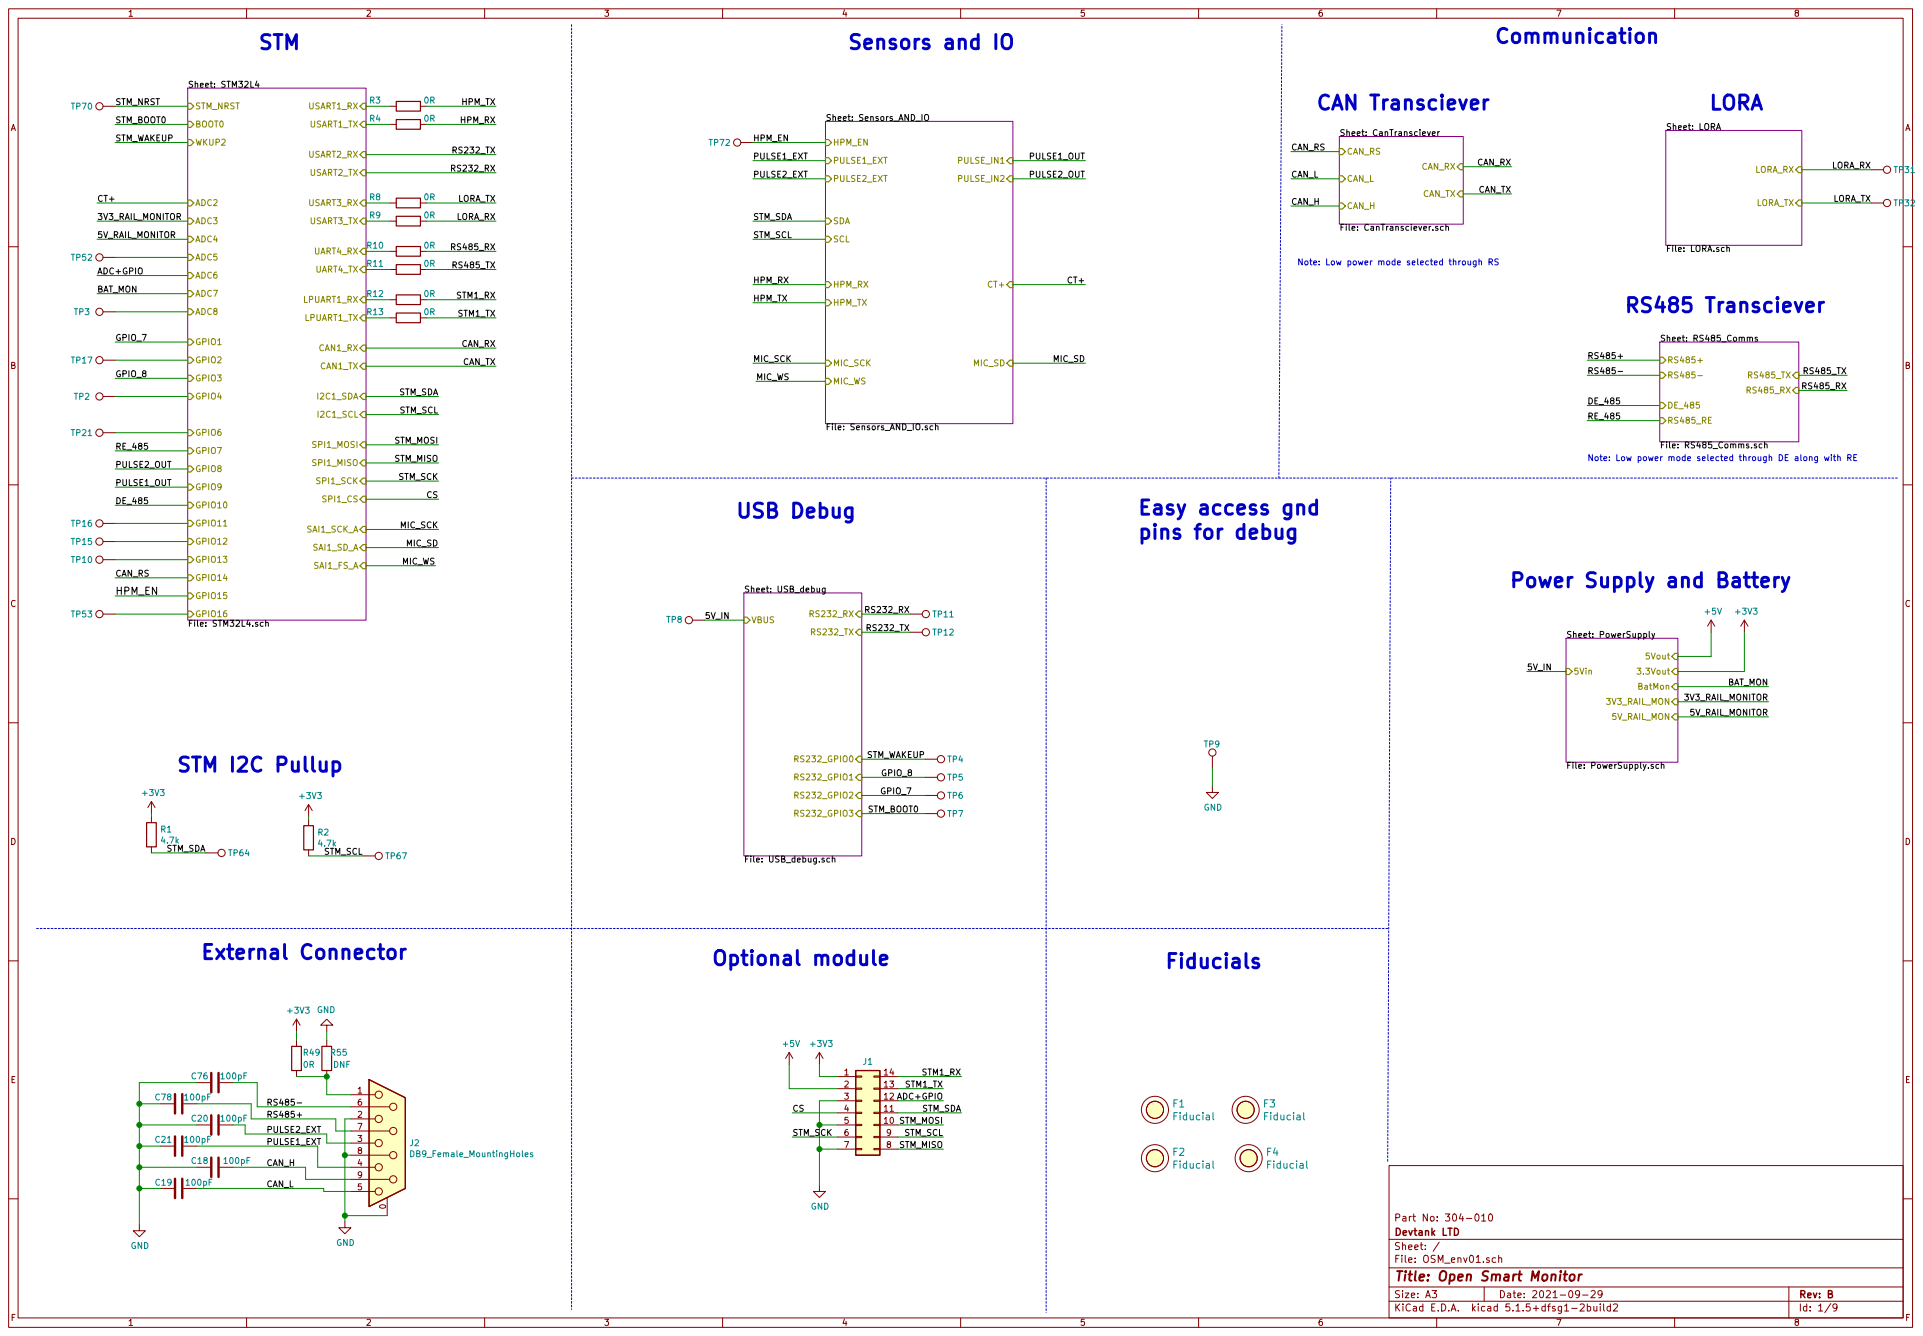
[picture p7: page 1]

Sheet: CanTransciever File: CanTransciever.sch CAN_RX CAN_TX CAN_L CAN_H
CAN_RS

Note: Low power mode selected through RS

Note: Low power mode selected through DE along with RE

Power Supply and Battery

Part No: 304-010
File: OSM_env01.sch Sheet: / Devtank LTD

Id: 1/9 Title: Open Smart Monitor

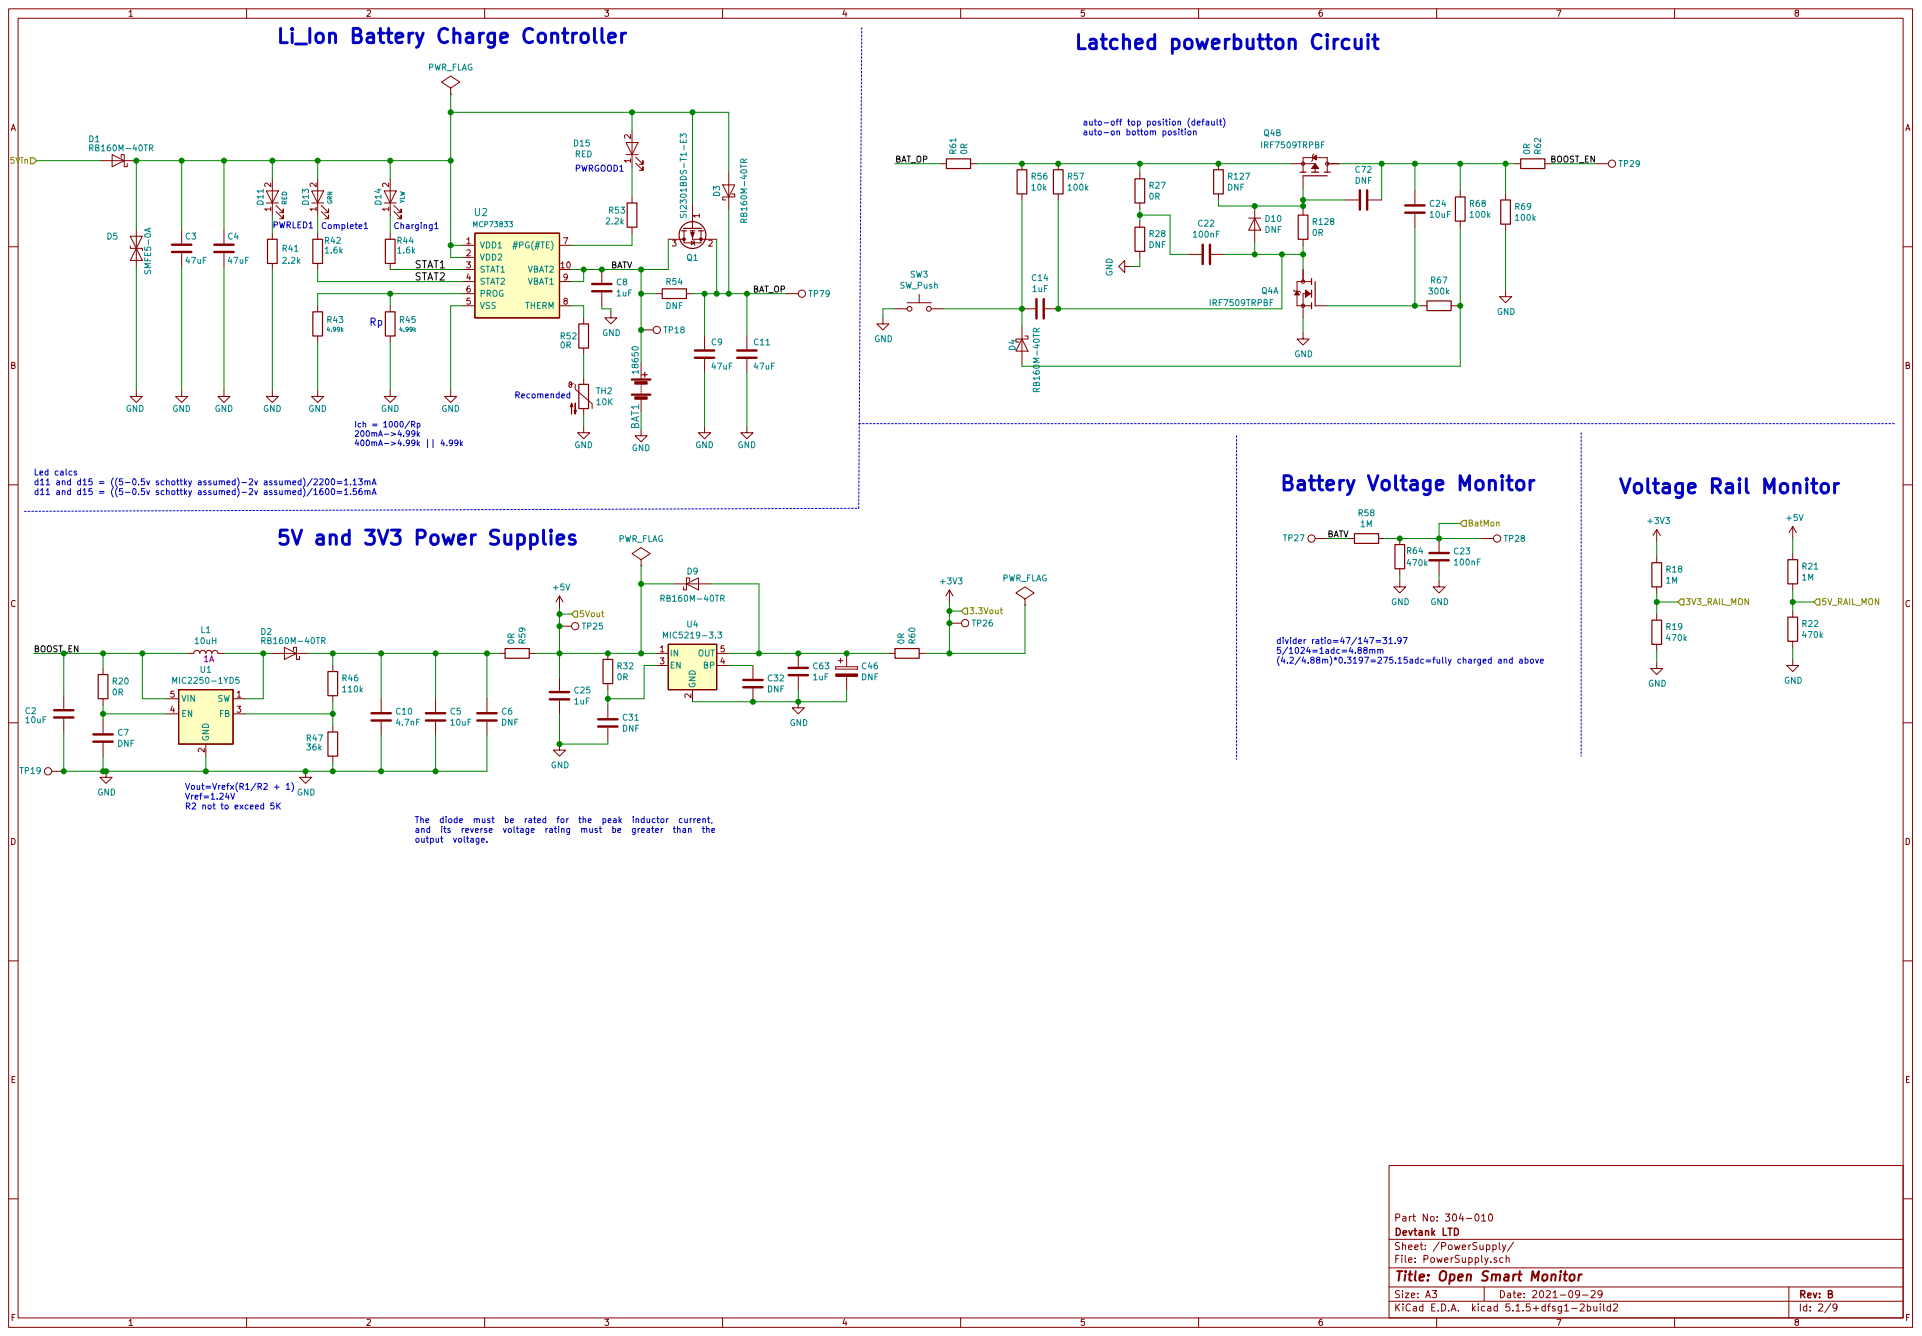
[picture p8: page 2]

auto-on bottom position
IRF7509TRPBF Q4A

2 FB 3 EN 4 VIN 5 U1 MIC2250-1YD5 GND GND

Led calcs d11 and d15 = ((5-0.5v schottky assumed)-2v assumed)/2200=1.13mA

BATV 5V and 3V3 Power Supplies

divider ratio=47/147=31.97
5/1024=1adc=4.88mm
(4.2/4.88m)*0.3197=275.15adc=fully charged and above

The diode must be rated for the peak inductor current,
and its reverse voltage rating must be greater than the
output voltage.

Part No: 304-010
Sheet: /PowerSupply/ Devtank LTD

File: PowerSupply.sch
Id: 2/9 Title: Open Smart Monitor

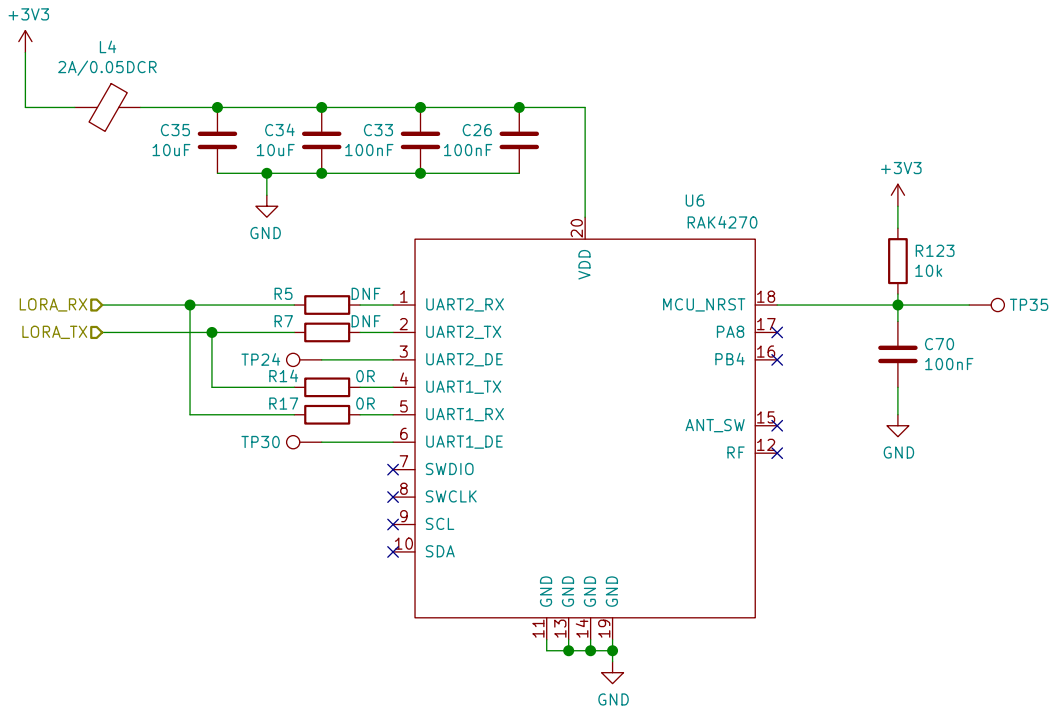
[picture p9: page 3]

Part No: 304-010
Id: 3/9 Title: Open Smart Monitor File: LORA.sch Sheet: /LORA/ Devtank LTD

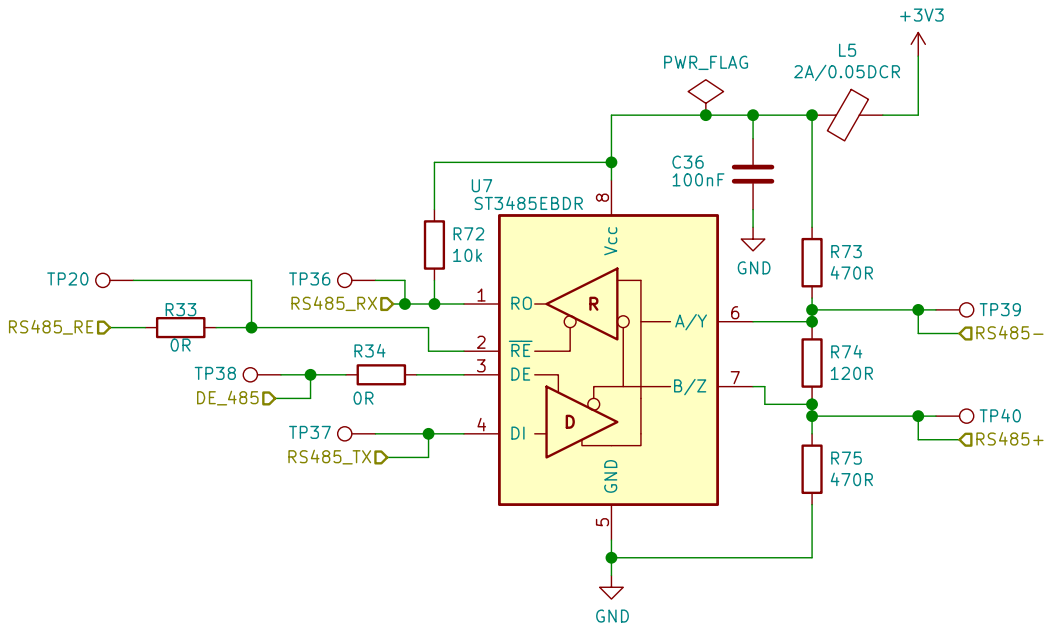
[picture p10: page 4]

File: RS485_Comms.sch
Id: 4/9 Title: Open Smart Monitor

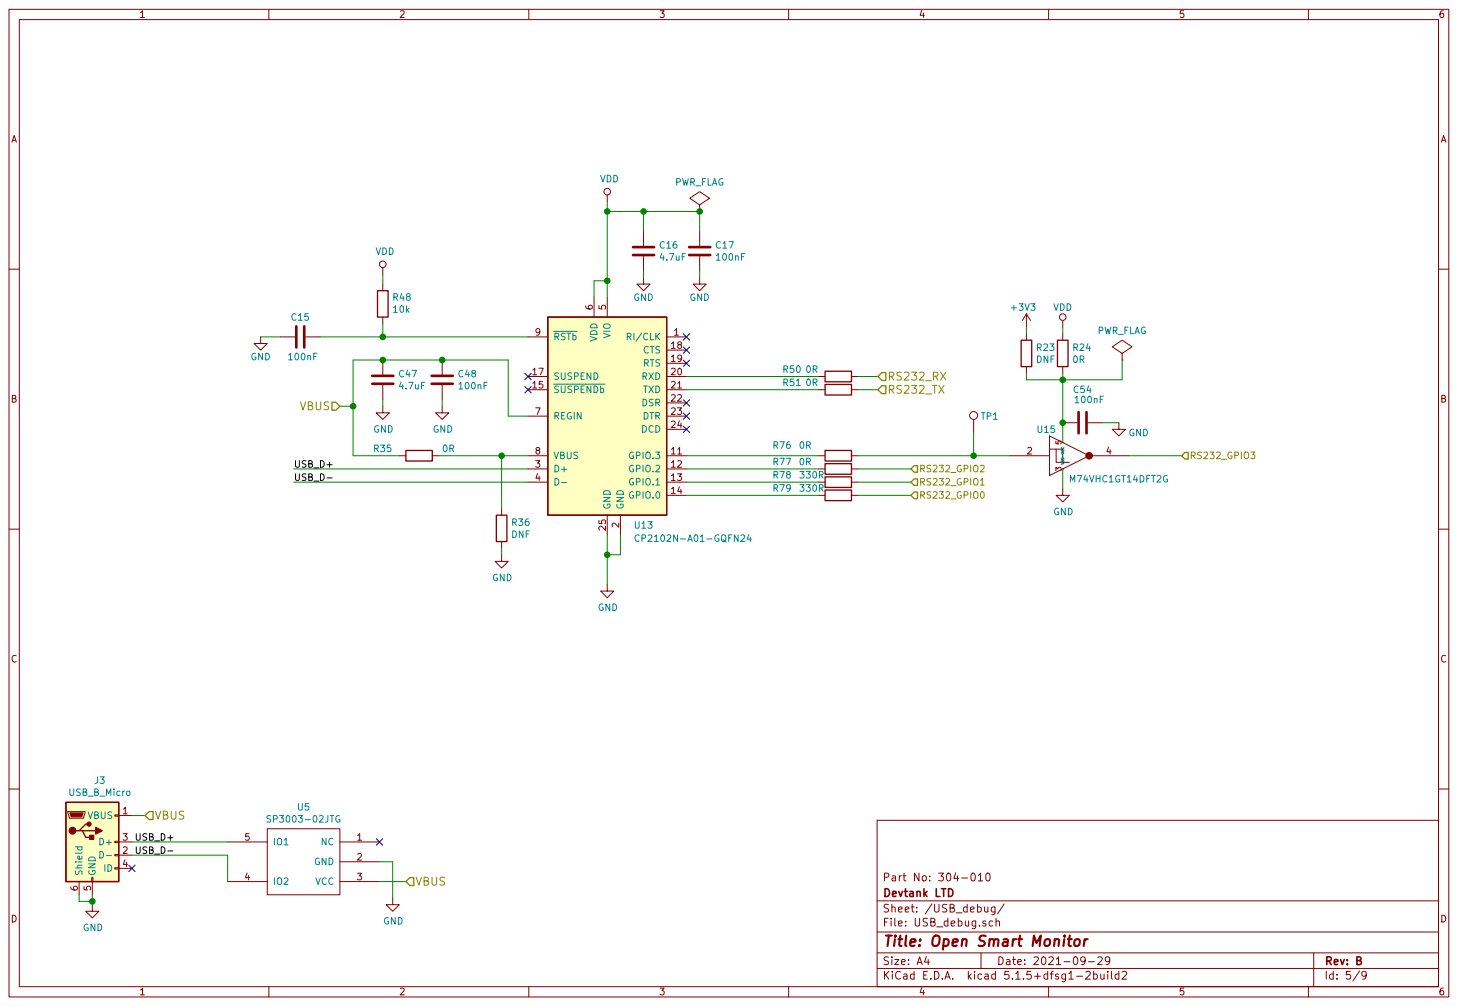
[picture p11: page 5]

6 REGIN 7 VBUS 8 RSTb 9 U13CP2102N-A01-GQFN24 GND

2 RXD 20 TXD 21 DSR 22 DTR 23 DCD 24 GND 25 D+ 3 D- 4 VIO

File: USB_debug.sch
Id: 5/9 Title: Open Smart Monitor

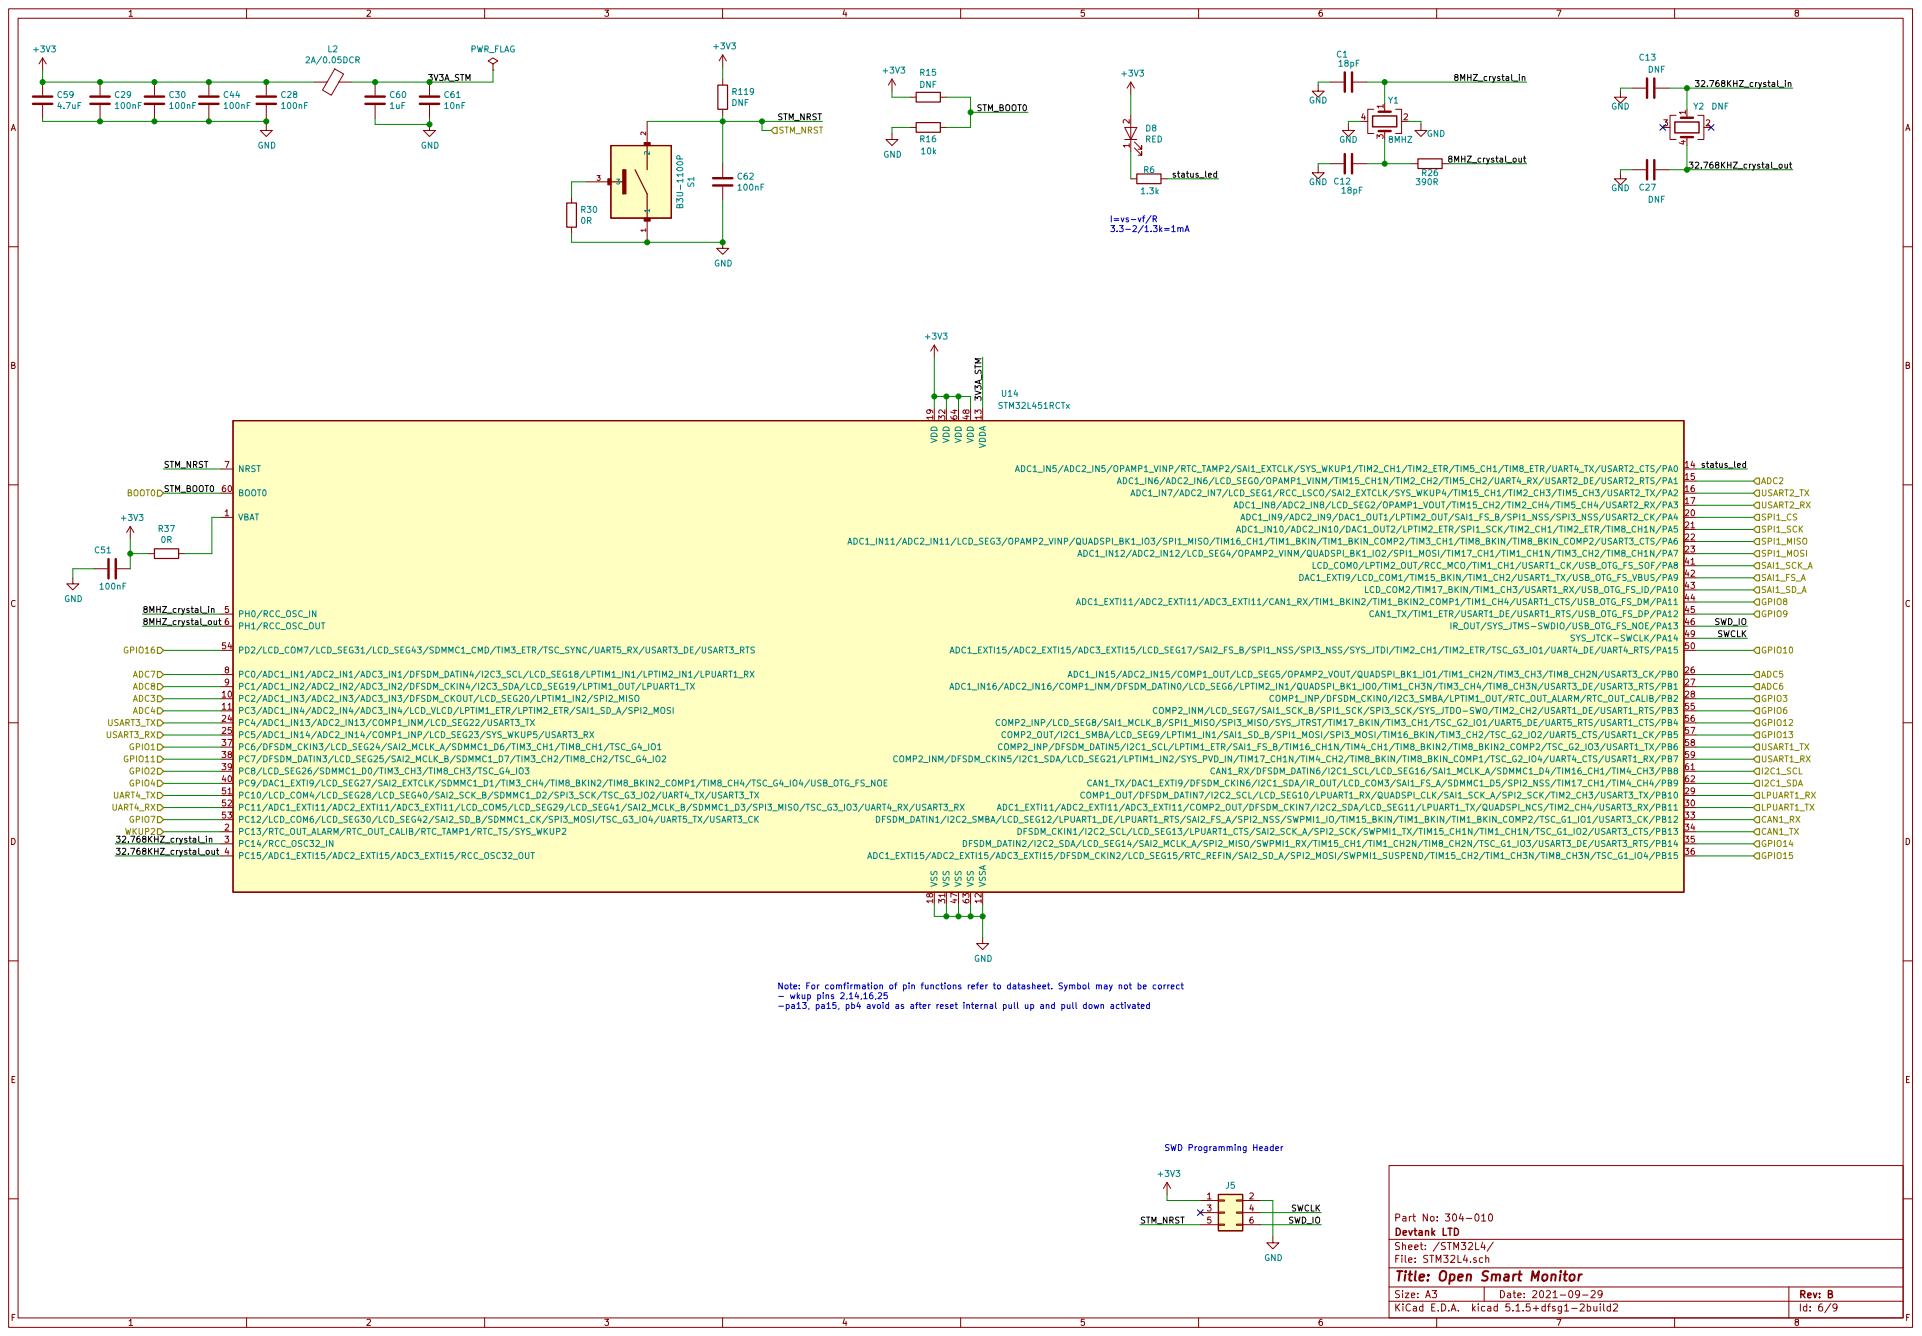
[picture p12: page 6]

Note: For comfirmation of pin functions refer to datasheet. Symbol may not be correct
- wkup pins 2,14,16,25
-pa13, pa15, pb4 avoid as after reset internal pull up and pull down activated

Part No: 304-010
Id: 6/9 Title: Open Smart Monitor File: STM32L4.sch Sheet: /STM32L4/ Devtank LTD

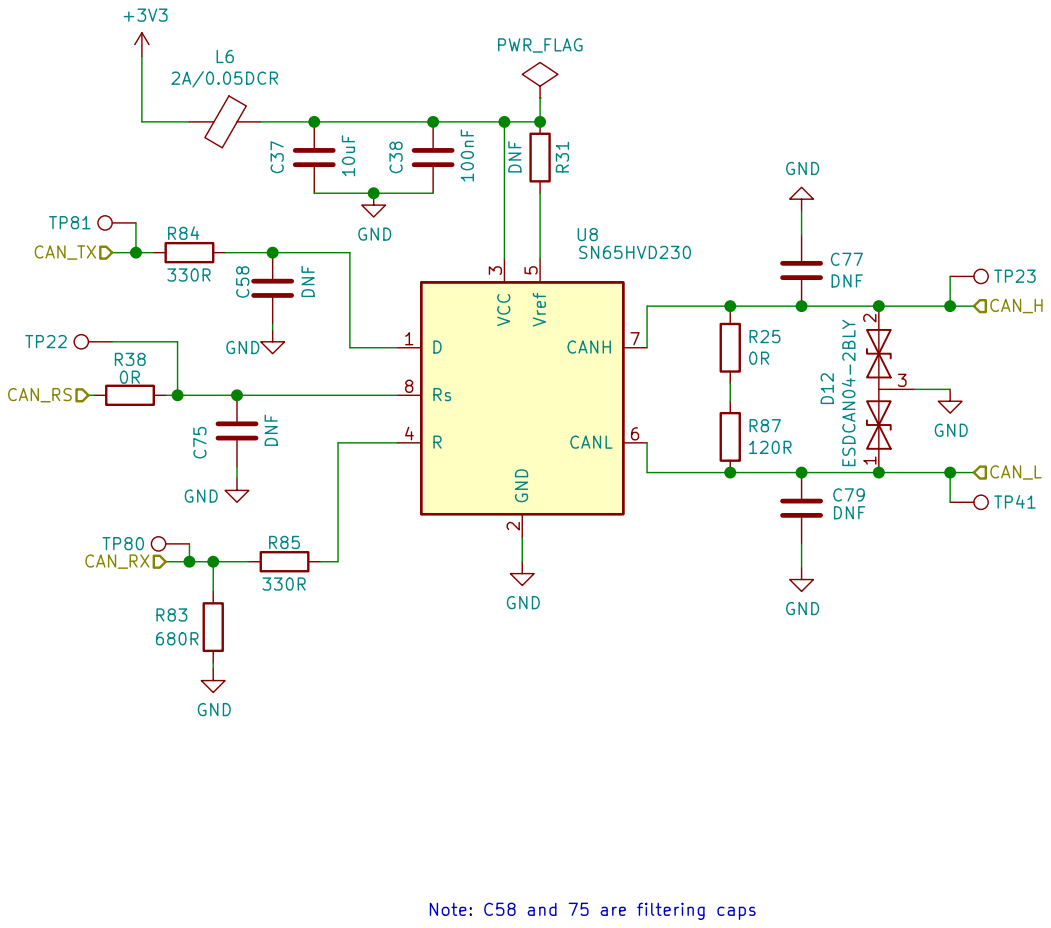
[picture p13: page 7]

C77 DNF GND GND GND

Part No: 304-010
Id: 7/9 Title: Open Smart Monitor File: CanTransciever.sch Sheet: /CanTransciever/ Devtank LTD

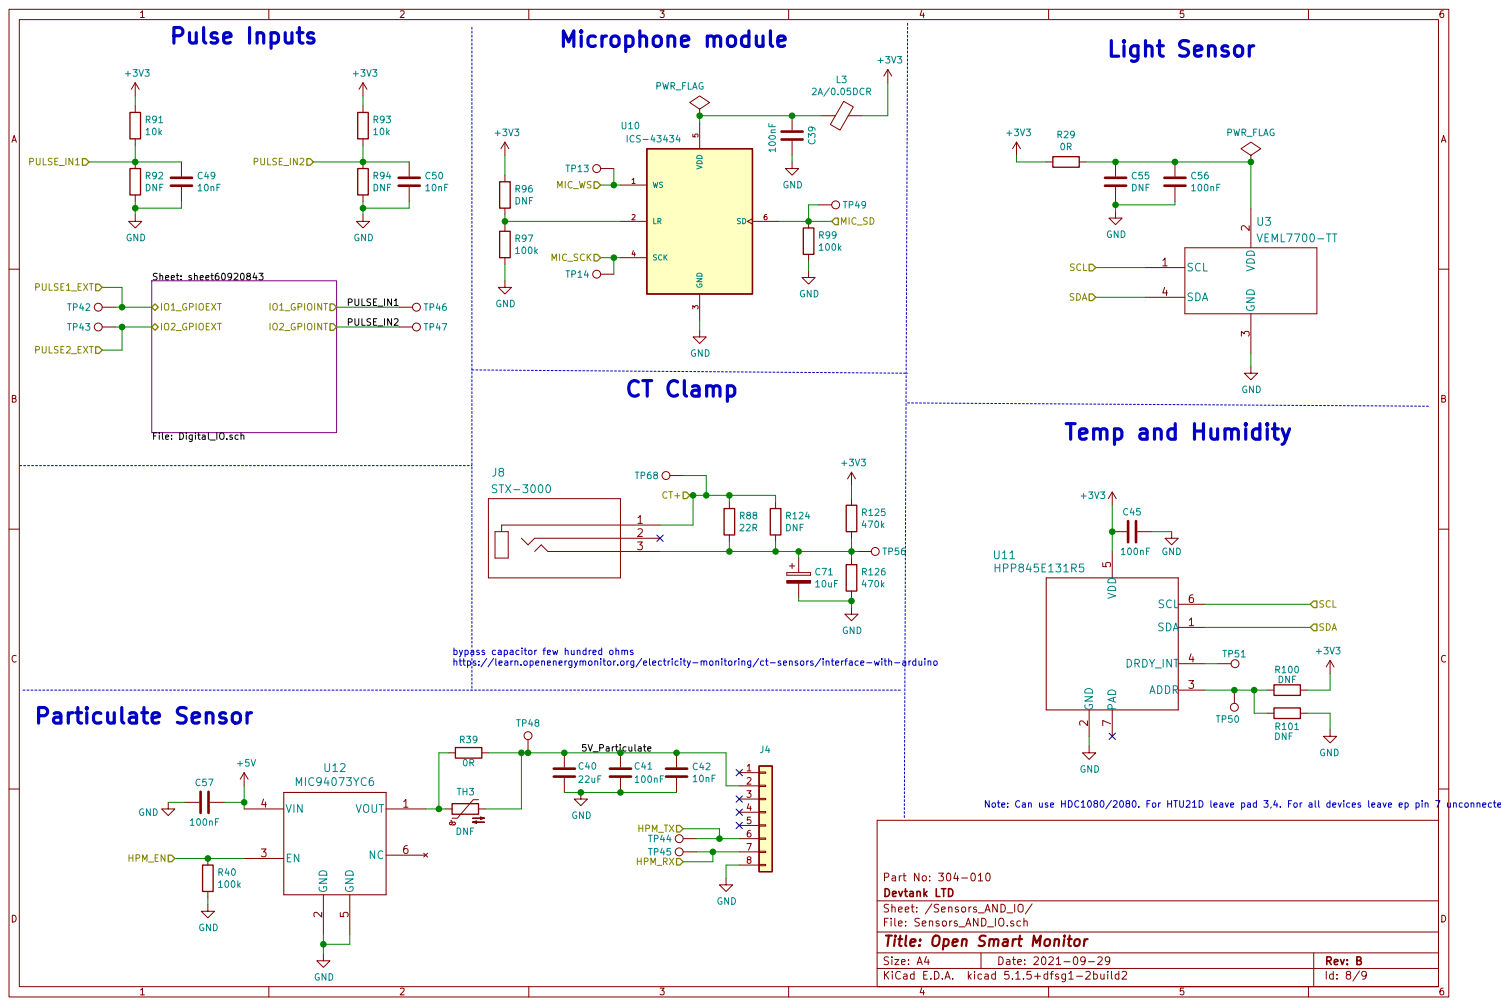
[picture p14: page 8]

bypass capacitor few hundred ohms
https://learn.openenergymonitor.org/electricity-monitoring/ct-sensors/interface-with-arduino

Note: Can use HDC1080/2080. For HTU21D leave pad 3,4. For all devices leave ep pin 7 unconnected

File: Sensors_AND_IO.sch
Id: 8/9 Title: Open Smart Monitor

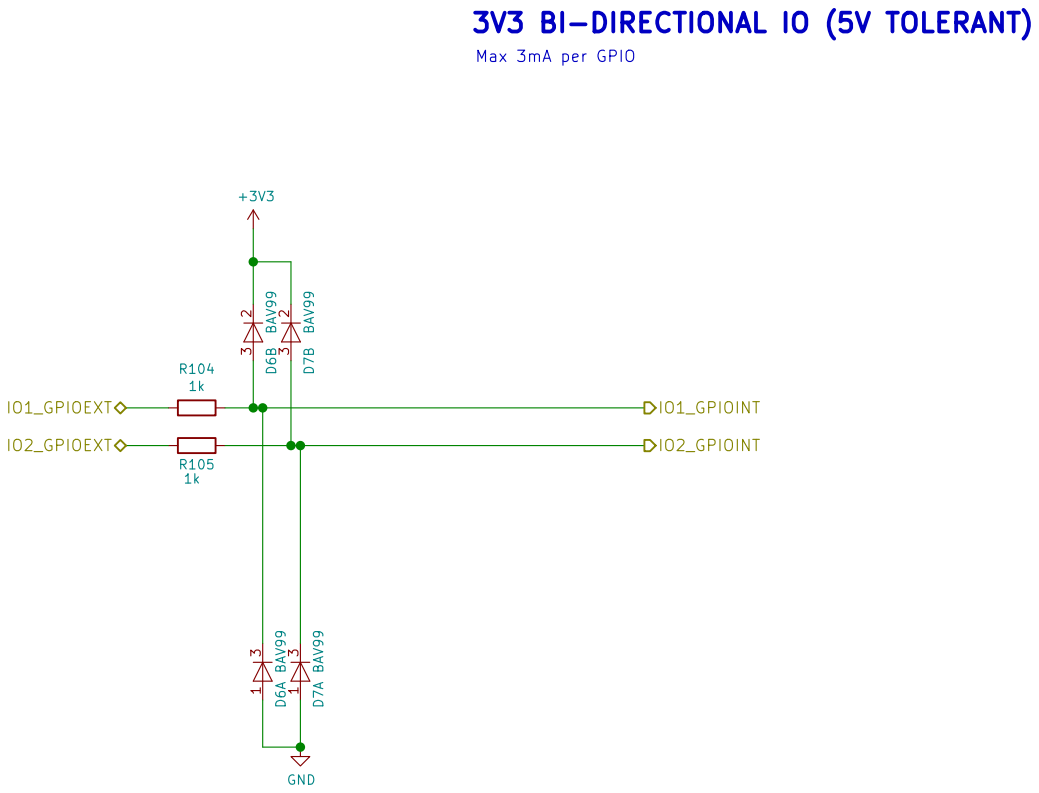
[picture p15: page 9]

3V3 BI-DIRECTIONAL IO (5V TOLERANT)

File: Digital_IO.sch
Id: 9/9 Title: Open Smart Monitor

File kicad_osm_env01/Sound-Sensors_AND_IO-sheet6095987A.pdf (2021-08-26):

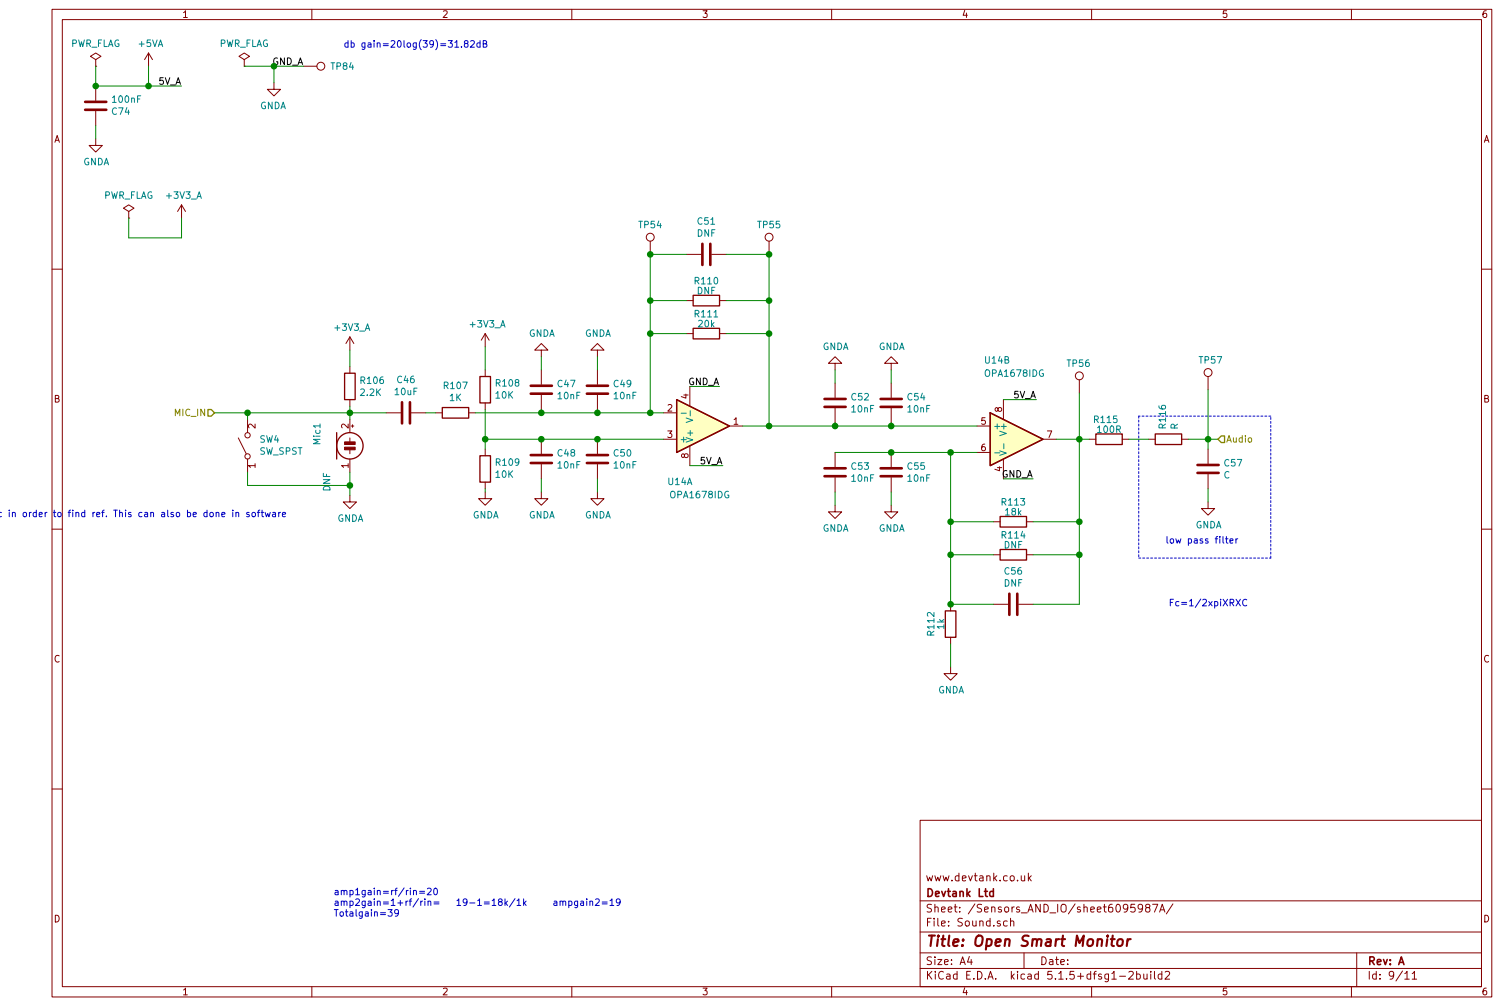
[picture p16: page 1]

5V_A Manual switch to gnd mic in order to find ref. This can also be done in software

Id: 9/11 Title: Open Smart Monitor File: Sound.sch Sheet: /Sensors_AND_IO/sheet6095987A/ Devtank Ltd www.devtank.co.uk

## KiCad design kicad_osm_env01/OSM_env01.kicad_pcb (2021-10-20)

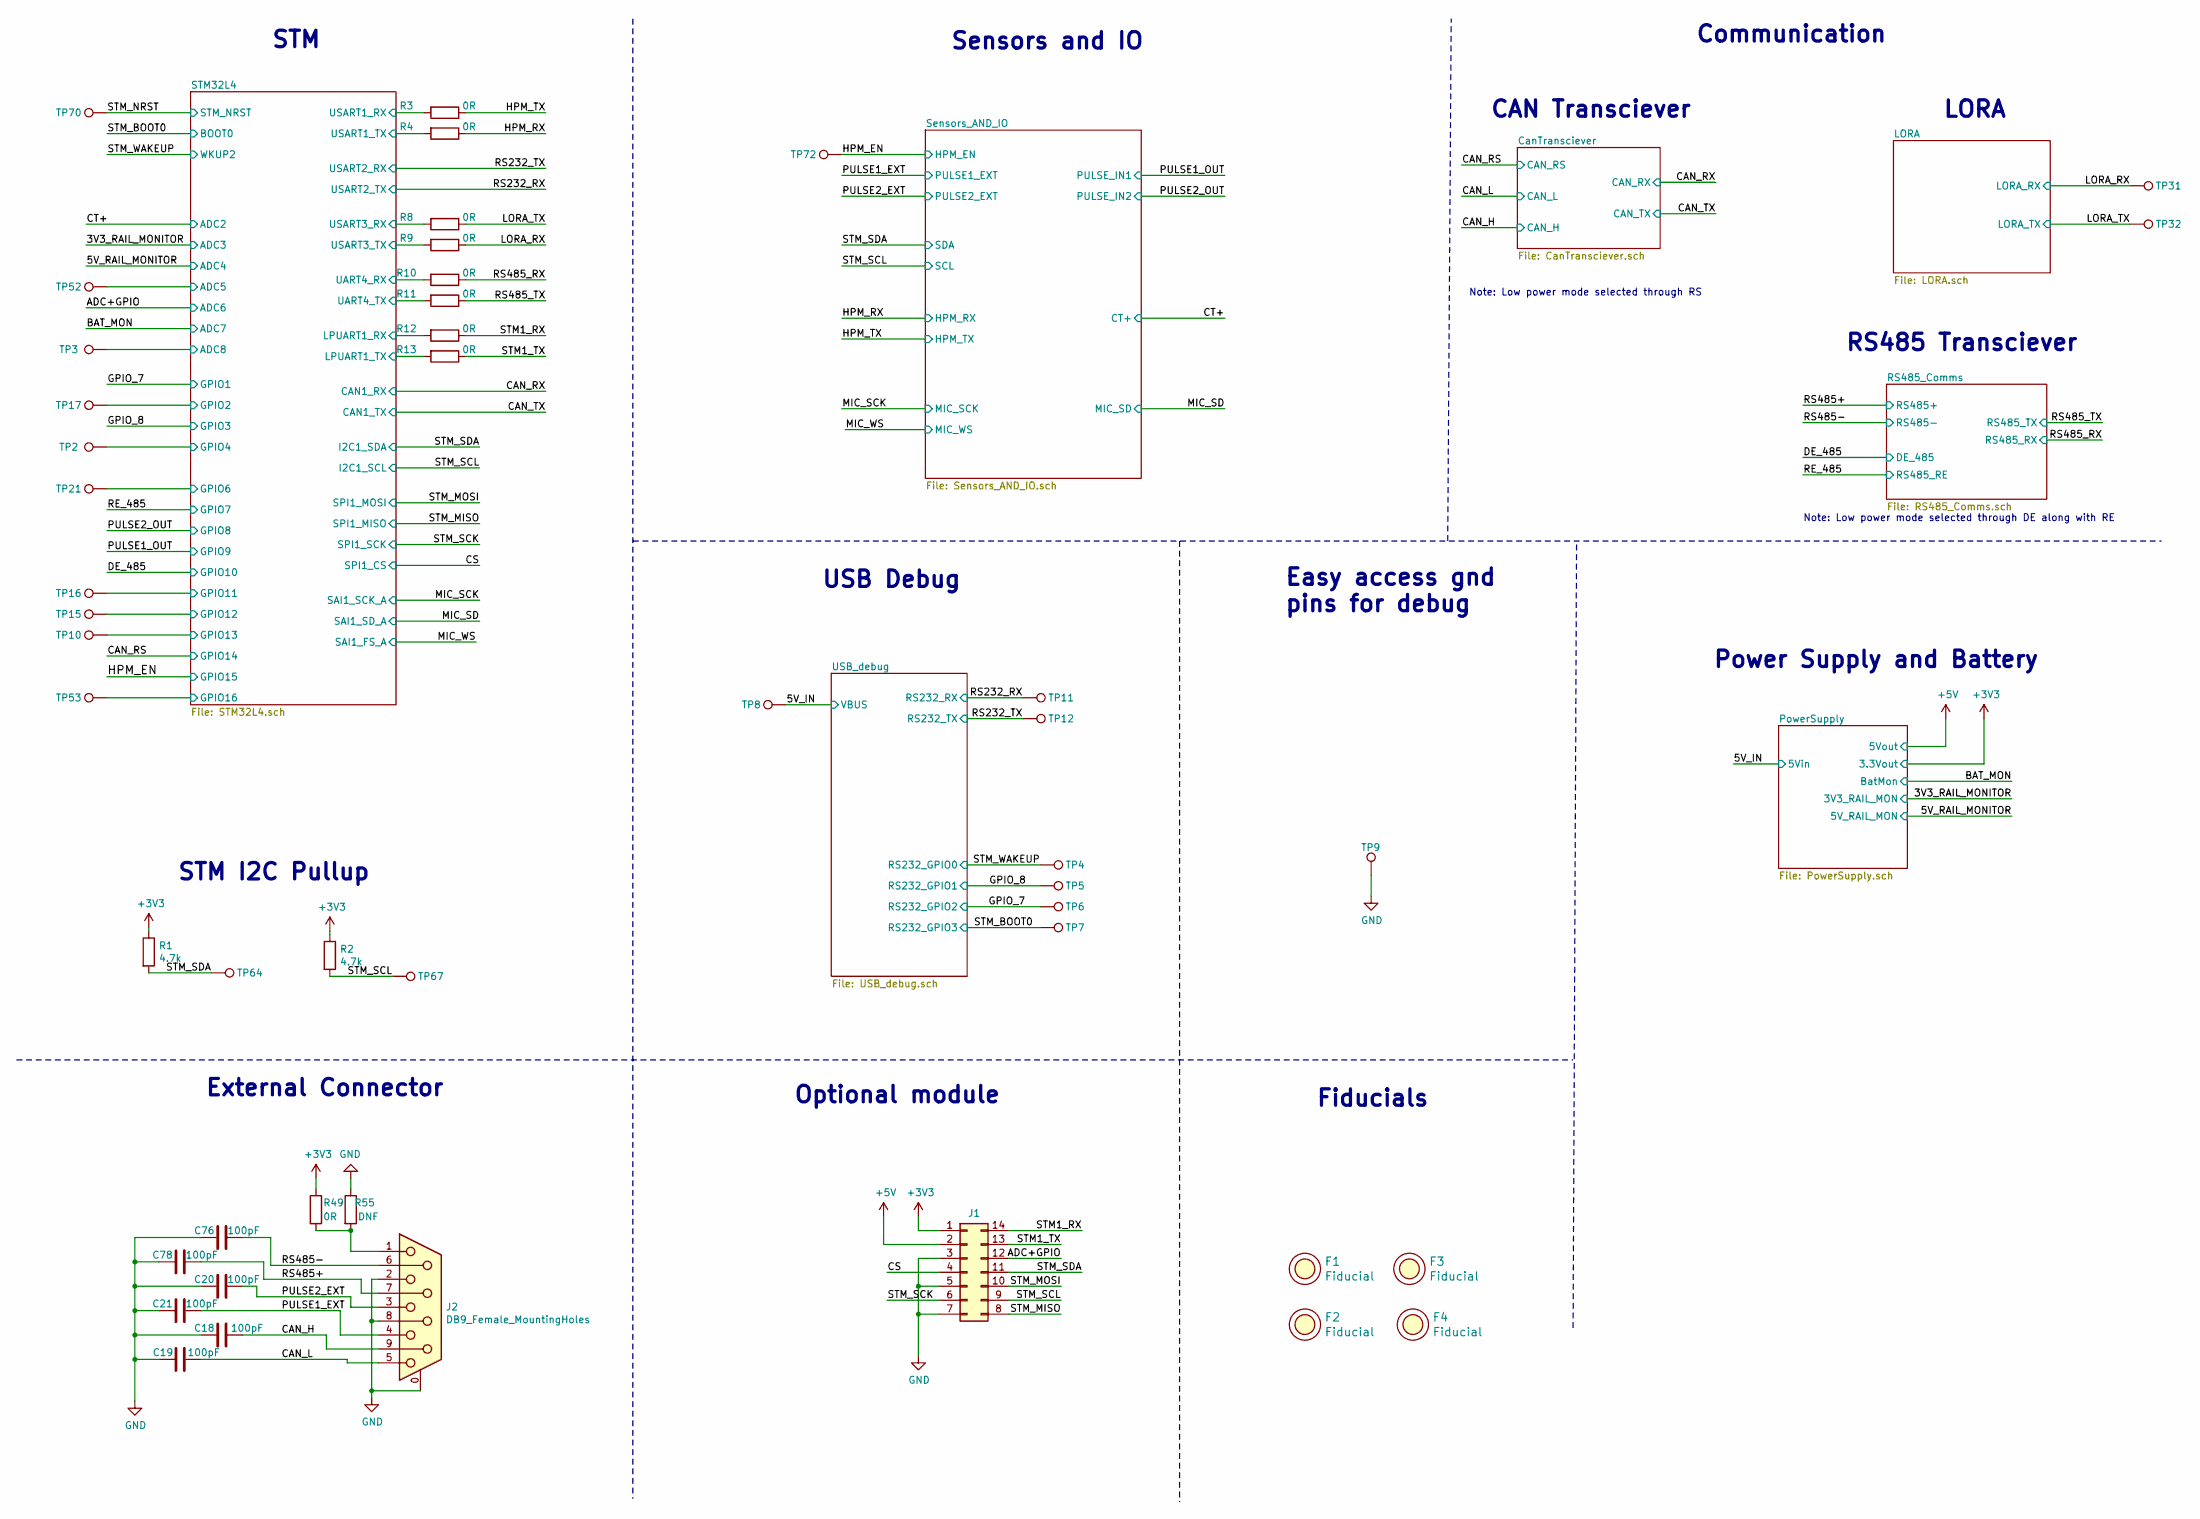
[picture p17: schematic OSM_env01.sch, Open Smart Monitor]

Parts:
C18, C19, C20, C21, C76, C78: 100pF; C_0402_1005Metric
F1, F2, F3, F4: Fiducial; Fiducial_1mm_Mask2mm
J1: Conn_02x07_Counter_Clockwise; PinSocket_2x07_P2.54mm_Vertical
J2: DB9_Female_MountingHoles; DSUB-9_Female_Horizontal_P2.77x2.84mm_EdgePinOffset7.70mm_H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
R1, R2: 4.7k; R_0603_1608Metric
R3, R4, R8, R9, R10, R11, R12, R13, R49: 0R; R_0603_1608Metric
R55: DNF; R_0603_1608Metric
TP2, TP3, TP10, TP15, TP16, TP17, TP21, TP52, TP53, TP64, TP67, TP70: Test_Point; TestPoint_Pad_D1.0mm
TP4, TP5, TP6, TP7, TP11, TP12: Test_Point; TestPoint_Pad_D1.5mm
TP8, TP31, TP32, TP72: Test_Point; TestPoint_THTPad_D1.0mm_Drill0.5mm
TP9: Test_Point; TestPoint_THTPad_4.0x4.0mm_Drill2.0mm

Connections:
+5V: J1.2; also elsewhere on the board
/5V_IN: TP8.1; also elsewhere on the board
/ADC+GPIO: J1.12; also elsewhere on the board
/CAN_H: C18.2, J2.9; also elsewhere on the board
/CAN_L: C19.1, J2.5; also elsewhere on the board
/CS: J1.4; also elsewhere on the board
/GPIO_7: TP6.1; also elsewhere on the board
/GPIO_8: TP5.1; also elsewhere on the board
/HPM_EN: TP72.1; also elsewhere on the board
/HPM_RX: R4.1; also elsewhere on the board
/HPM_TX: R3.1; also elsewhere on the board
/LORA_RX: R9.1, TP31.1; also elsewhere on the board
/LORA_TX: R8.1, TP32.1; also elsewhere on the board
/PULSE1_EXT: C21.2, J2.4; also elsewhere on the board
/PULSE2_EXT: C20.2, J2.3; also elsewhere on the board
/RS232_RX: TP11.1; also elsewhere on the board
/RS232_TX: TP12.1; also elsewhere on the board
/RS485+: C78.2, J2.7; also elsewhere on the board
/RS485-: C76.2, J2.6; also elsewhere on the board
/RS485_RX: R10.1; also elsewhere on the board
/RS485_TX: R11.1; also elsewhere on the board
/STM1_RX: J1.14, R12.1
/STM1_TX: J1.13, R13.1
/STM32L4/ADC5: TP52.1; also elsewhere on the board
/STM32L4/ADC8: TP3.1; also elsewhere on the board
/STM32L4/GPIO2: TP17.1; also elsewhere on the board
/STM32L4/GPIO4: TP2.1; also elsewhere on the board
/STM32L4/GPIO6: TP21.1; also elsewhere on the board
/STM32L4/GPIO11: TP16.1; also elsewhere on the board
/STM32L4/GPIO12: TP15.1; also elsewhere on the board
/STM32L4/GPIO13: TP10.1; also elsewhere on the board
/STM32L4/GPIO16: TP53.1; also elsewhere on the board
/STM32L4/LPUART1_RX: R12.2; also elsewhere on the board
/STM32L4/LPUART1_TX: R13.2; also elsewhere on the board
/STM32L4/UART4_RX: R10.2; also elsewhere on the board
/STM32L4/UART4_TX: R11.2; also elsewhere on the board
/STM32L4/USART1_RX: R3.2; also elsewhere on the board
/STM32L4/USART1_TX: R4.2; also elsewhere on the board
/STM32L4/USART3_RX: R8.2; also elsewhere on the board
/STM32L4/USART3_TX: R9.2; also elsewhere on the board
/STM_BOOT0: TP7.1; also elsewhere on the board
/STM_MISO: J1.8; also elsewhere on the board
/STM_MOSI: J1.10; also elsewhere on the board
/STM_NRST: TP70.1; also elsewhere on the board
/STM_SCK: J1.6; also elsewhere on the board
/STM_SCL: J1.9, R2.2, TP67.1; also elsewhere on the board
/STM_SDA: J1.11, R1.2, TP64.1; also elsewhere on the board
/STM_WAKEUP: TP4.1; also elsewhere on the board
unnamed: J2.1, R49.2, R55.2

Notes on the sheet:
External Connector
STM I2C Pullup
Optional module
Easy access gnd pins for debug
STM
USB Debug
LORA
RS485 Transciever
Sensors and IO
Power Supply and Battery
Fiducials
Note: Low power mode selected through DE along with RE
Communication
CAN Transciever
Note: Low power mode selected through RS

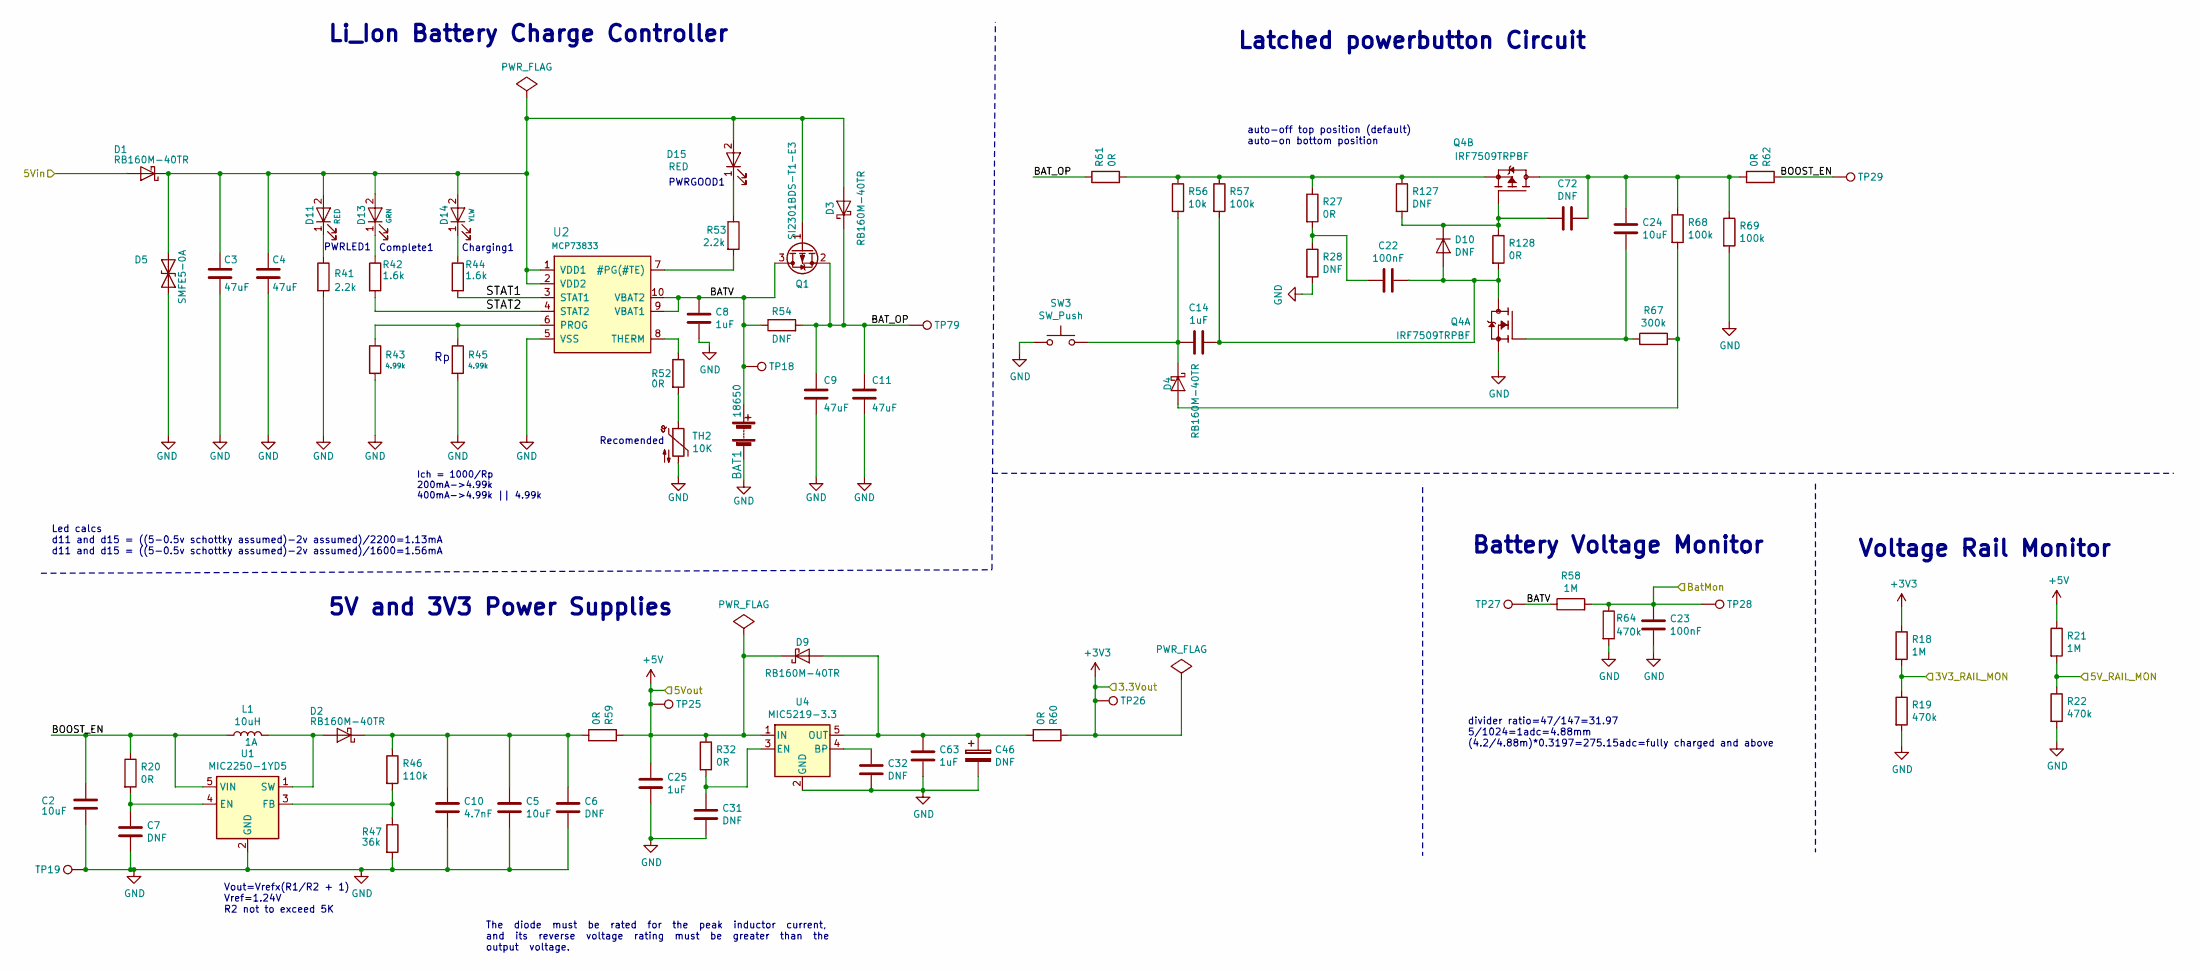
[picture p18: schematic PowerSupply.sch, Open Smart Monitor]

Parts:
BAT1: 18650; BatteryHolder_Keystone_1042_1x18650
C2: 10uF; C_0603_1608Metric; Voltage 10V
C3, C4, C9, C11: 47uF; C_0805_2012Metric
C5, C24: 10uF; C_0603_1608Metric
C6, C7, C31: DNF; C_0603_1608Metric
C8, C14, C25, C63: 1uF; C_0402_1005Metric
C10: 4.7nF; C_0402_1005Metric
C22, C23: 100nF; C_0402_1005Metric
C32, C72: DNF; C_0402_1005Metric
C46: DNF; CP_Elec_4x5.4
D1, D2, D3, D4, D9: RB160M-40TR; D_SOD-123
D5: SMFE5-0A; D_SOD-123
D10: DNF; D_SOD-123
D11, D15: RED; LED_0603_1608Metric
D13: GRN; LED_Rectangular_W4.5mm_H7.3mm_Horizontal_2.54mm_Z3.0mm
D14: YLW; LED_Rectangular_W4.5mm_H7.3mm_Horizontal_2.54mm_Z3.0mm
L1: 10uH; L_1812_4532Metric
Q1: SI2301BDS-T1-E3; SOT-23
Q4: IRF7509TRPBF; SO-8_3.9x4.9mm_P1.27mm
R18, R21, R58: 1M; R_0603_1608Metric
R19, R22, R64: 470k; R_0603_1608Metric
R20, R27, R32, R52, R128: 0R; R_0603_1608Metric
R28, R54, R127: DNF; R_0603_1608Metric
R41, R53: 2.2k; R_0603_1608Metric
R42, R44: 1.6k; R_0603_1608Metric
R43, R45: 4.99k; R_0603_1608Metric
R46: 110k; R_0603_1608Metric
R47: 36k; R_0603_1608Metric
R56: 10k; R_0603_1608Metric
R57, R68, R69: 100k; R_0603_1608Metric
R59, R60, R61, R62: 0R; R_0805_2012Metric
R67: 300k; R_0603_1608Metric
SW3: SW_Push; SW_Tactile_SPST_Angled_PTS645Vx58-2LFS
TH2: 10K; R_1206_3216Metric
TP18, TP27, TP28, TP29, TP79: Test_Point; TestPoint_Pad_D1.5mm
TP19, TP25, TP26: Test_Point; TestPoint_THTPad_D1.0mm_Drill0.5mm
U1: MIC2250-1YD5; SOT-23-5
U2: MCP73833; MSOP-10_3x3mm_P0.5mm
U4: MIC5219-3.3; SOT-23-5

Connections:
+5V: C25.1, D9.1 (K), R21.1, R32.1, R59.1, TP25.1, U4.1 (IN); also elsewhere on the board
/3V3_RAIL_MONITOR: R18.2, R19.1; also elsewhere on the board
/5V_IN: D1.2 (A); also elsewhere on the board
/5V_RAIL_MONITOR: R21.2, R22.1; also elsewhere on the board
/BAT_MON: C23.1, R58.2, R64.1, TP28.1; also elsewhere on the board
/PowerSupply/BATV: BAT1.1 (+), C8.1, Q1.3 (D), R54.1, R58.1, TP18.1, TP27.1, U2.9 (VBAT1), U2.10 (VBAT2)
/PowerSupply/BAT_OP: C9.1, C11.1, D3.1 (K), Q1.2 (S), R54.2, R61.1, TP79.1
/PowerSupply/BOOST_EN: C2.1, L1.1, R20.1, R62.1, TP29.1, U1.5 (VIN)
/PowerSupply/STAT1: R44.2, U2.3 (STAT1)
/PowerSupply/STAT2: R42.2, U2.4 (STAT2)
unnamed: C7.1, R20.2, U1.4 (EN)
unnamed: C5.1, C6.1, C10.1, D2.1 (K), R46.1, R59.2
unnamed: C14.1, D4.1 (K), R56.2, SW3.2
unnamed: C14.2, C22.2, D10.2 (A), Q4.7 (D), Q4.8 (D), R57.2, R128.2
unnamed: C22.1, R27.2, R28.1
unnamed: C24.1, C72.1, Q4.5 (D), Q4.6 (D), R62.2, R68.1, R69.1
unnamed: C24.2, Q4.2 (G), R67.1
unnamed: C31.1, R32.2, U4.3 (EN)
unnamed: C32.1, U4.4 (BP)
unnamed: C46.1, C63.1, D9.2 (A), R60.2, U4.5 (OUT)
unnamed: C72.2, D10.1 (K), Q4.4 (G), R127.2, R128.1
unnamed: D2.2 (A), L1.2, U1.1 (SW)
unnamed: D4.2 (A), R67.2, R68.2
unnamed: D11.1 (K), R41.1
unnamed: D13.1 (K), R42.1
unnamed: D15.1 (K), R53.1
unnamed: Q4.3 (S), R27.1, R56.1, R57.1, R61.2, R127.1
unnamed: R43.1, R45.1, U2.6 (PROG)
unnamed: R46.2, R47.1, U1.3 (FB)
unnamed: R52.1, U2.8 (THERM)
unnamed: R52.2, TH2.1
unnamed: R53.2, U2.7 (#PG(#TE))

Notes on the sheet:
Vout=Vrefx(R1/R2 + 1) Vref=1.24V R2 not to exceed 5K
auto-off top position (default) auto-on bottom position
divider ratio=47/147=31.97 5/1024=1adc=4.88mm (4.2/4.88m)*0.3197=275.15adc=fully charged and above
The diode must be rated for the peak inductor current, and its reverse voltage rating must be greater than the output voltage.
Li_Ion Battery Charge Controller
Ich = 1000/Rp 200mA->4.99k 400mA->4.99k || 4.99k
Latched powerbutton Circuit
Battery Voltage Monitor
Voltage Rail Monitor
5V and 3V3 Power Supplies
Complete1
Charging1
PWRLED1
PWRGOOD1
Led calcs d11 and d15 = ((5-0.5v schottky assumed)-2v assumed)/2200=1.13mA d11 and d15 = ((5-0.5v schottky assumed)-2v assumed)/1600=1.56mA
Recomended

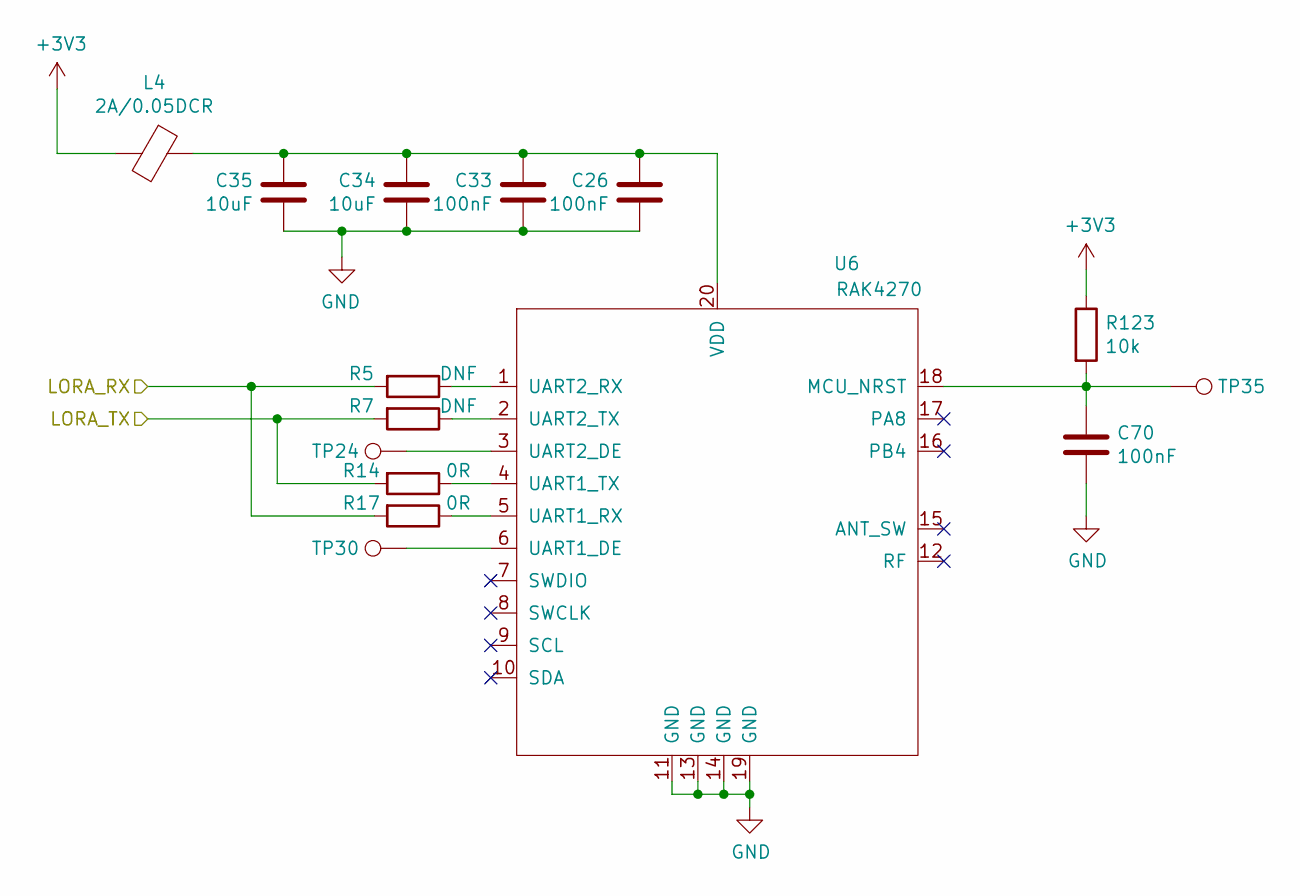
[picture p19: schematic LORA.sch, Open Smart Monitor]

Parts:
C26, C33, C70: 100nF; C_0402_1005Metric
C34, C35: 10uF; C_0603_1608Metric
L4: 2A/0.05DCR; L_0402_1005Metric
R5, R7: DNF; R_0603_1608Metric
R14, R17: 0R; R_0603_1608Metric
R123: 10k; R_0603_1608Metric
TP24, TP30, TP35: Test_Point; TestPoint_THTPad_D1.0mm_Drill0.5mm
U6: RAK4270; RAK4270_WisDuo_LPWAN_Module

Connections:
/LORA_RX: R5.2, R17.2; also elsewhere on the board
/LORA_TX: R7.2, R14.2; also elsewhere on the board
unnamed: C26.1, C33.1, C34.1, C35.1, L4.1, U6.20 (VDD)
unnamed: C70.1, R123.2, TP35.1, U6.18 (MCU_NRST)
unnamed: R5.1, U6.1 (UART2_RX)
unnamed: R7.1, U6.2 (UART2_TX)
unnamed: R14.1, U6.4 (UART1_TX)
unnamed: R17.1, U6.5 (UART1_RX)
unnamed: TP24.1, U6.3 (UART2_DE)
unnamed: TP30.1, U6.6 (UART1_DE)

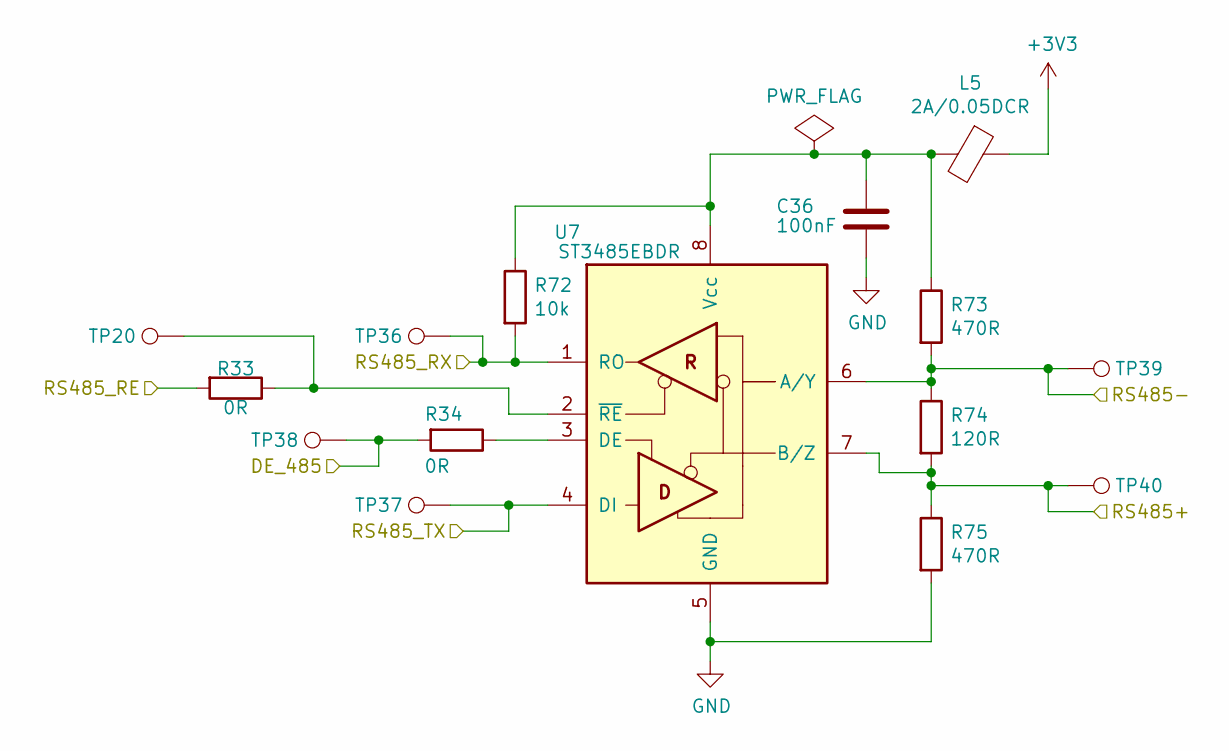
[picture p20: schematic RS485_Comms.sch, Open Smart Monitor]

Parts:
C36: 100nF; C_0402_1005Metric
L5: 2A/0.05DCR; L_0402_1005Metric
R33, R34: 0R; R_0603_1608Metric
R72: 10k; R_0603_1608Metric
R73, R75: 470R; R_0603_1608Metric
R74: 120R; R_0603_1608Metric
TP20, TP36, TP37, TP38, TP39, TP40: Test_Point; TestPoint_Pad_D1.5mm
U7: ST3485EBDR; SOIC-8_3.9x4.9mm_P1.27mm

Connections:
/DE_485: R34.2, TP38.1; also elsewhere on the board
/RE_485: R33.2; also elsewhere on the board
/RS485+: R74.2, R75.1, TP40.1, U7.7 (B/Z); also elsewhere on the board
/RS485-: R73.2, R74.1, TP39.1, U7.6 (A/Y); also elsewhere on the board
/RS485_RX: R72.2, TP36.1, U7.1 (RO); also elsewhere on the board
/RS485_TX: TP37.1, U7.4 (DI); also elsewhere on the board
unnamed: C36.1, L5.2, R72.1, R73.1, U7.8 (Vcc)
unnamed: R33.1, TP20.1, U7.2 (~RE)
unnamed: R34.1, U7.3 (DE)

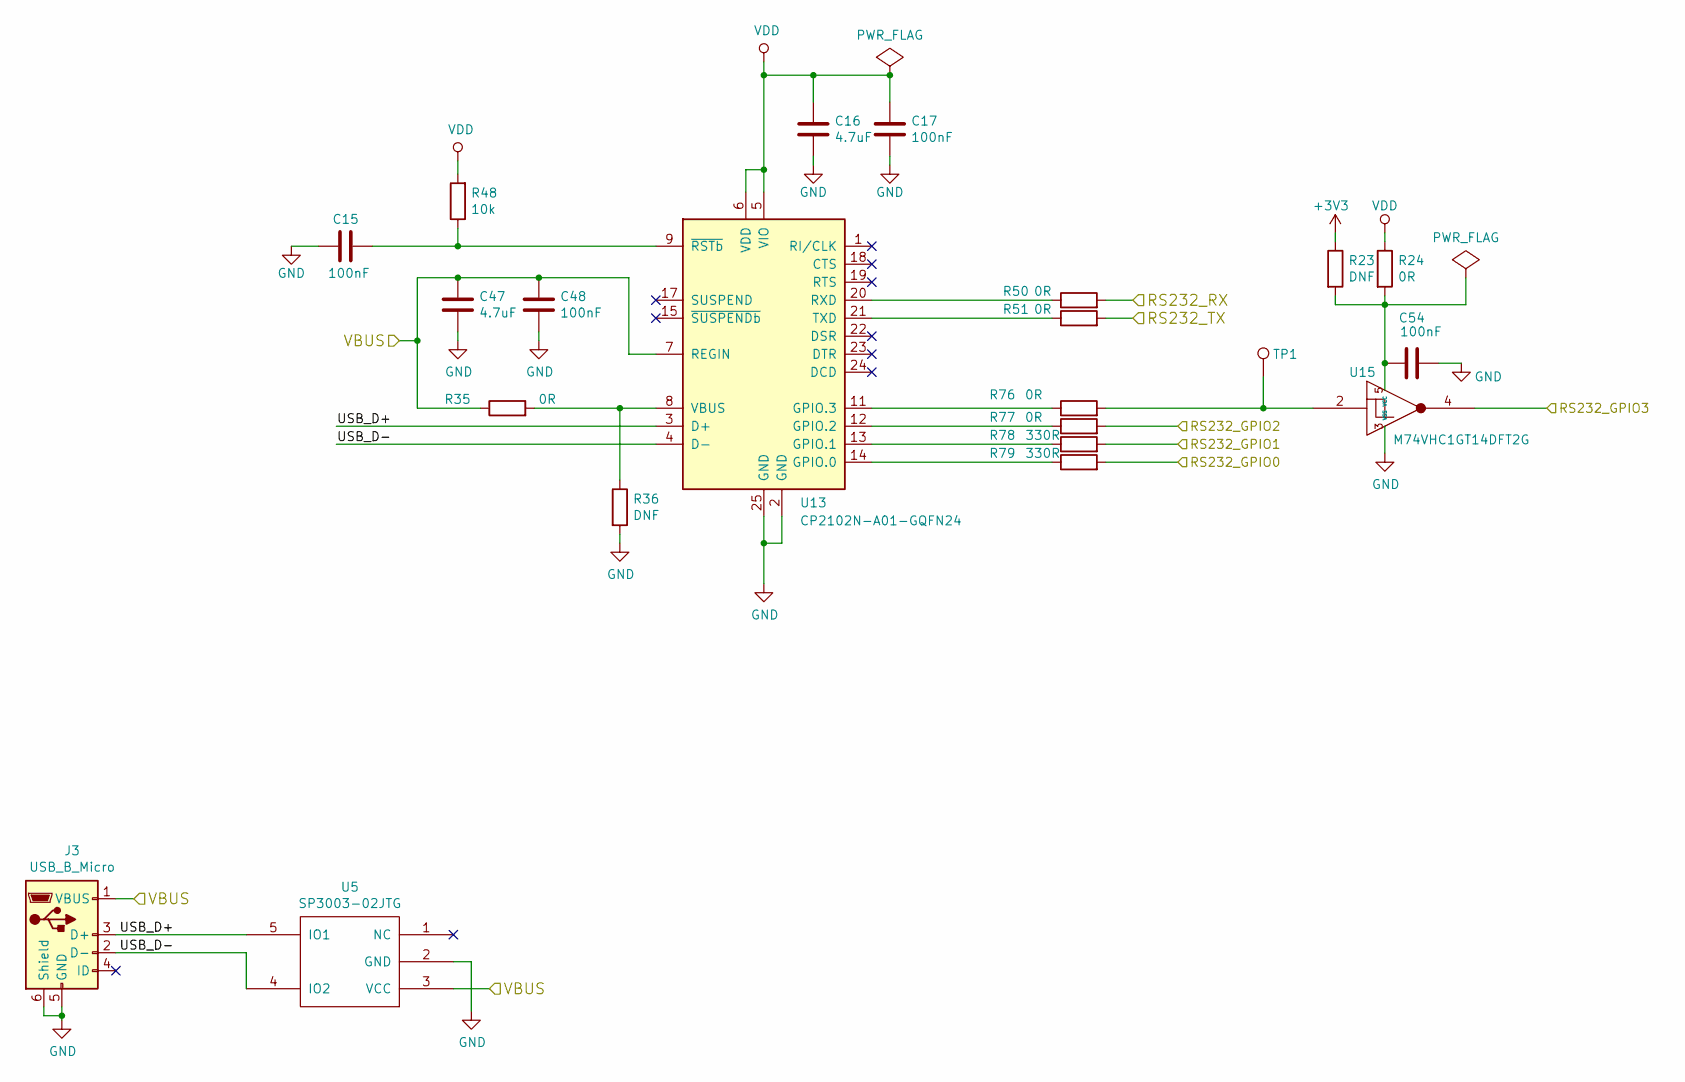
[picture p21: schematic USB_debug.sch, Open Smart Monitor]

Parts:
C15, C17, C48, C54: 100nF; C_0402_1005Metric
C16, C47: 4.7uF; C_0603_1608Metric
J3: USB_B_Micro; MOLEX_105017-0001_USB_B
R23, R36: DNF; R_0603_1608Metric
R24, R35, R50, R51, R76, R77: 0R; R_0603_1608Metric
R48: 10k; R_0603_1608Metric
R78, R79: 330R; R_0603_1608Metric
TP1: Test_Point; TestPoint_Pad_D1.5mm
U5: SP3003-02JTG; SOT-353_SC-70-5
U13: CP2102N-A01-GQFN24; CP2102_QFN-24-1EP_4x4mm_P0.5mm_EP2.6x2.6mm_ThermalVias_0.3m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
U15: M74VHC1GT14DFT2G; SOT-353_SC-70-5

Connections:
/5V_IN: C47.1, C48.1, J3.1 (VBUS), R35.1, U5.3 (VCC), U13.7 (REGIN); also elsewhere on the board
/GPIO_7: R77.2; also elsewhere on the board
/GPIO_8: R78.2; also elsewhere on the board
/RS232_RX: R50.2; also elsewhere on the board
/RS232_TX: R51.2; also elsewhere on the board
/STM_BOOT0: U15.4; also elsewhere on the board
/STM_WAKEUP: R79.2; also elsewhere on the board
/USB_debug/USB_D+: J3.3 (D+), U5.5 (IO1), U13.3 (D+)
/USB_debug/USB_D-: J3.2 (D-), U5.4 (IO2), U13.4 (D-)
unnamed: C15.1, R48.1, U13.9 (~RSTb)
unnamed: C54.2, R23.2, R24.2, U15.5 (VCC)
unnamed: R35.2, R36.1, U13.8 (VBUS)
unnamed: R50.1, U13.20 (RXD)
unnamed: R51.1, U13.21 (TXD)
unnamed: R76.1, U13.11 (GPIO.3)
unnamed: R76.2, TP1.1, U15.2
unnamed: R77.1, U13.12 (GPIO.2)
unnamed: R78.1, U13.13 (GPIO.1)
unnamed: R79.1, U13.14 (GPIO.0)
VDD: C16.1, C17.1, R24.1, R48.2, U13.5 (VIO), U13.6 (VDD)

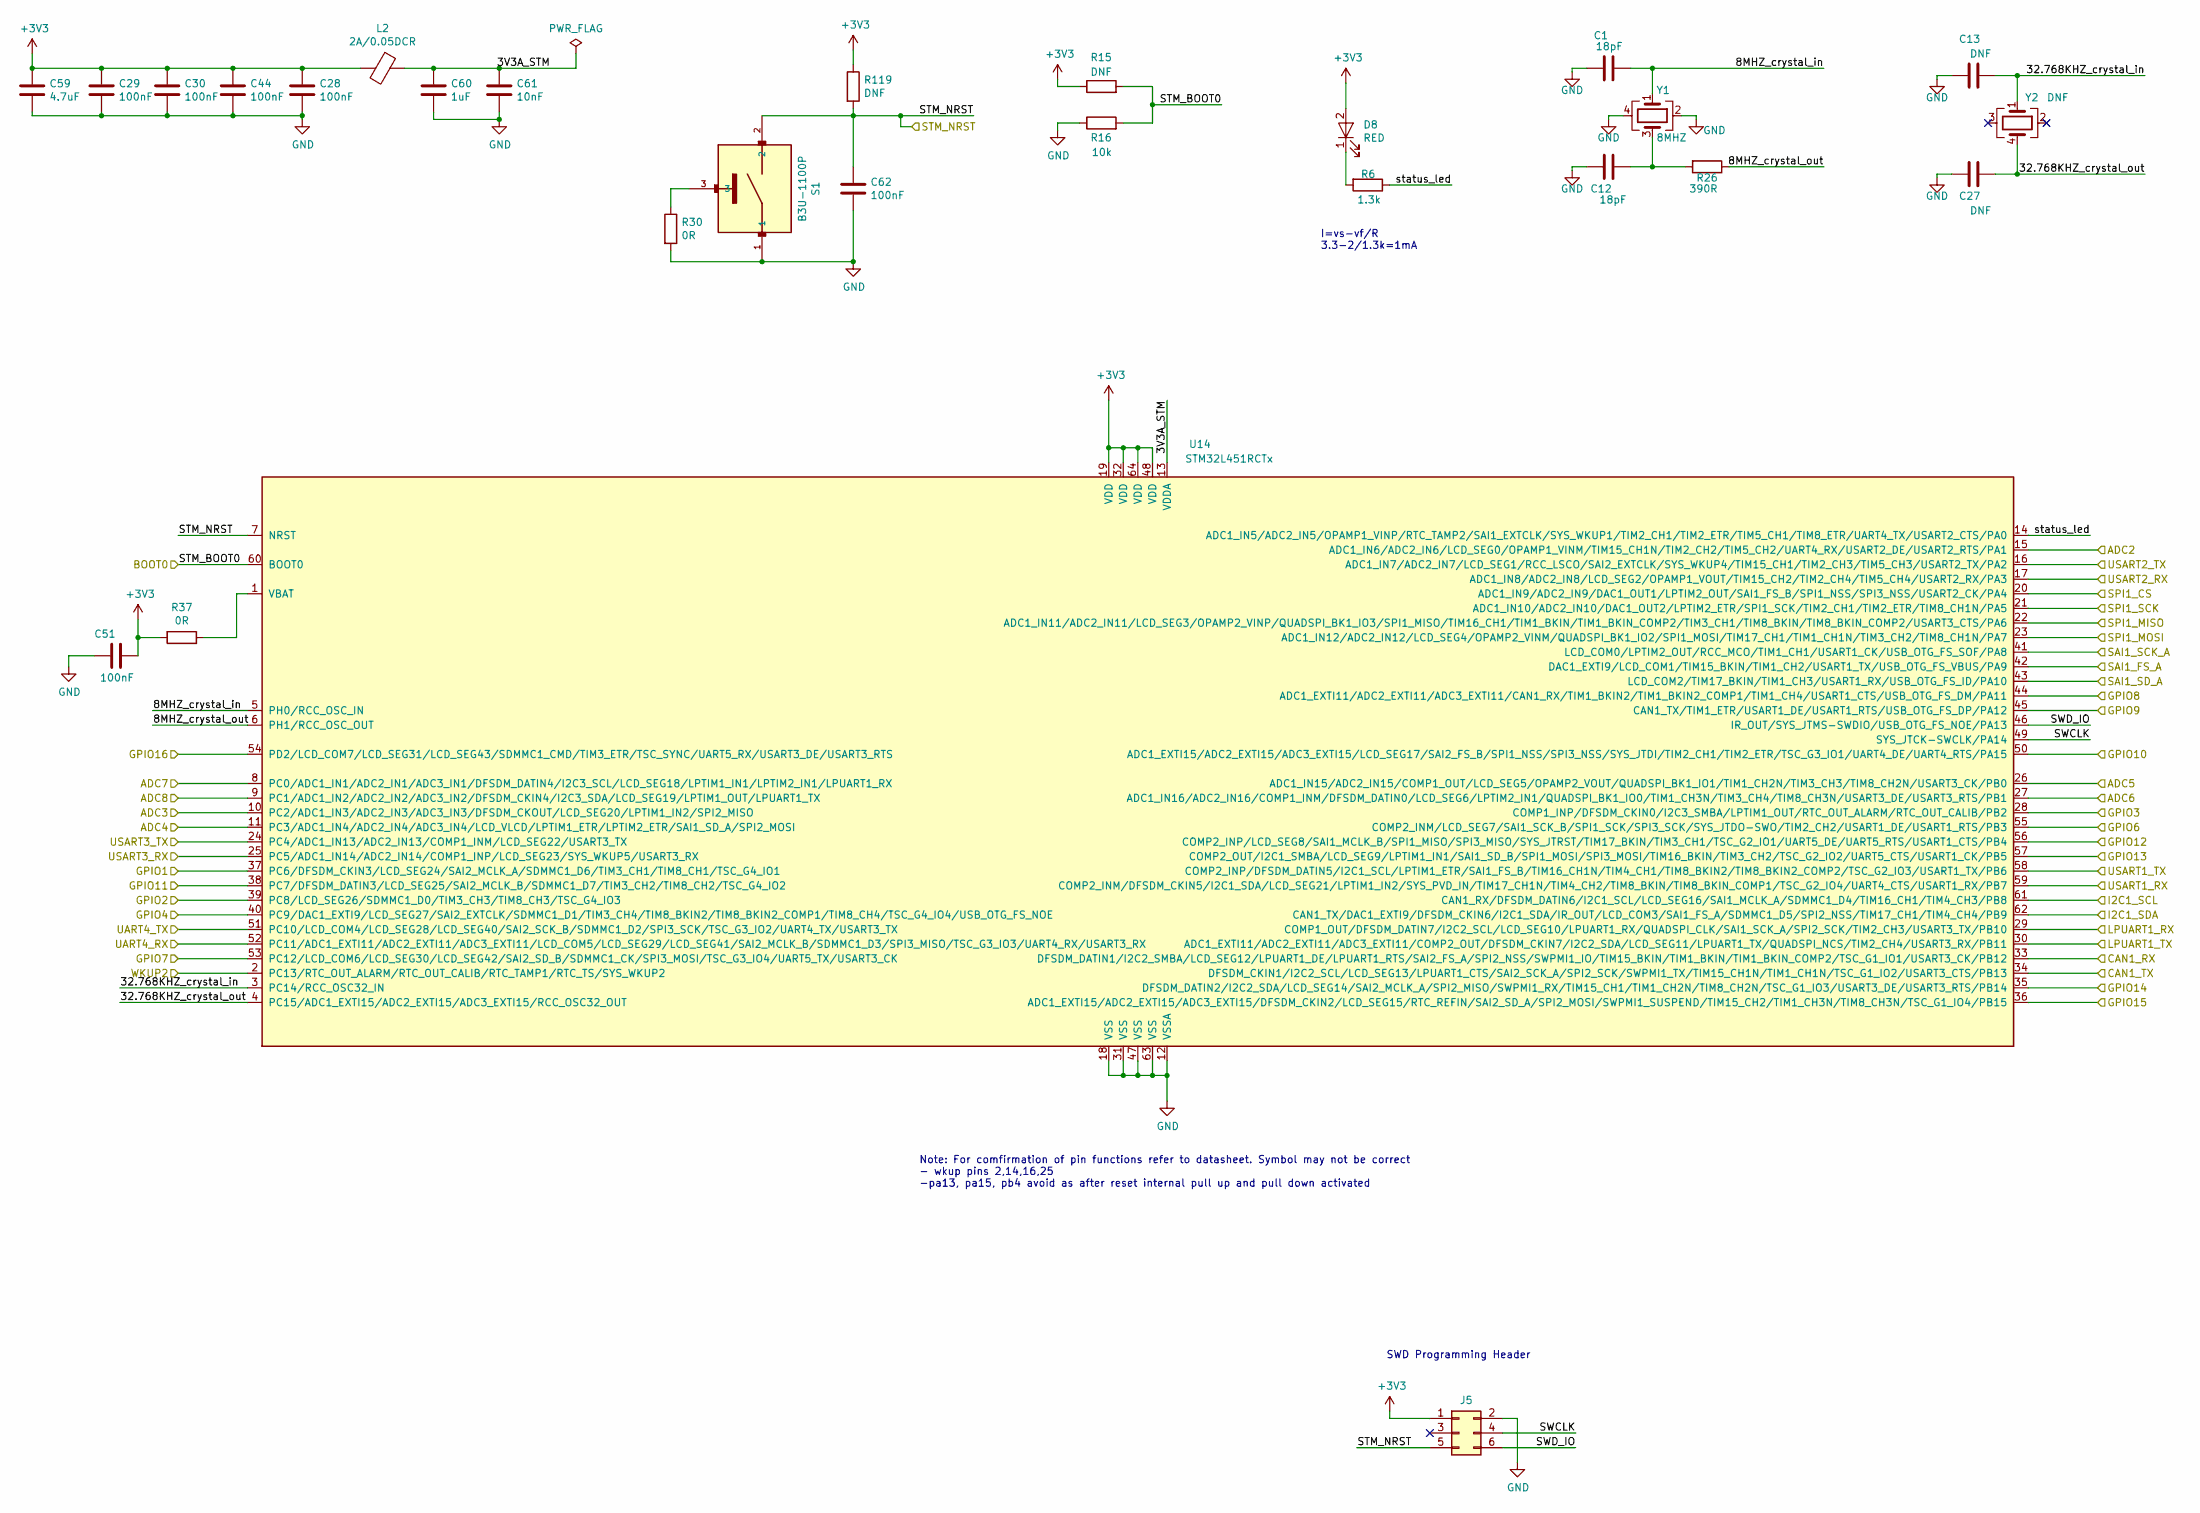
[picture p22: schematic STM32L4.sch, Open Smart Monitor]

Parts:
C1, C12: 18pF; C_0402_1005Metric
C13, C27: DNF; C_0402_1005Metric
C28, C29, C30, C44, C51, C62: 100nF; C_0402_1005Metric
C59: 4.7uF; C_0603_1608Metric
C60: 1uF; C_0402_1005Metric
C61: 10nF; C_0402_1005Metric
D8: RED; LED_Rectangular_W4.5mm_H7.3mm_Horizontal_2.54mm_Z3.0mm
J5: Conn_02x03_Odd_Even; Tag-Connect_TC2030-IDC-NL_2x03_P1.27mm_Vertical
L2: 2A/0.05DCR; L_0402_1005Metric
R6: 1.3k; R_0603_1608Metric
R15, R119: DNF; R_0603_1608Metric
R16: 10k; R_0603_1608Metric
R26: 390R; R_0603_1608Metric
R30, R37: 0R; R_0603_1608Metric
S1: B3U-1100P; SW_SPST_B3U-1100P
U14: STM32L451RCTx; LQFP-64_10x10mm_P0.5mm
Y1: 8MHZ; Crystal_SMD_Abracon_ABM3C-4Pin_5.0x3.2mm
Y2: DNF; Crystal_SMD_7050-4Pin_7.0x5.0mm

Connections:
/3V3_RAIL_MONITOR: U14.10 (PC2/ADC1_IN3/ADC2_IN3/ADC3_IN3/DFSDM_CK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); also elsewhere on the board
/5V_RAIL_MONITOR: U14.11 (PC3/ADC1_IN4/ADC2_IN4/ADC3_IN4/LCD_VLCD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); also elsewhere on the board
/ADC+GPIO: U14.27 (ADC1_IN16/ADC2_IN16/COMP1_INM/DFSDM_DAT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); also elsewhere on the board
/BAT_MON: U14.8 (PC0/ADC1_IN1/ADC2_IN1/ADC3_IN1/DFSDM_DA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); also elsewhere on the board
/CAN_RS: U14.35 (DFSDM_DATIN2/I2C2_SDA/LCD_SEG14/SAI2_MC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); also elsewhere on the board
/CAN_RX: U14.33 (DFSDM_DATIN1/I2C2_SMBA/LCD_SEG12/LPUART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); also elsewhere on the board
/CAN_TX: U14.34 (DFSDM_CKIN1/I2C2_SCL/LCD_SEG13/LPUART1_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); also elsewhere on the board
/CS: U14.20 (ADC1_IN9/ADC2_IN9/DAC1_OUT1/LPTIM2_OUT/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); also elsewhere on the board
/CT+: U14.15 (ADC1_IN6/ADC2_IN6/LCD_SEG0/OPAMP1_VINM/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); also elsewhere on the board
/DE_485: U14.50 (ADC1_EXTI15/ADC2_EXTI15/ADC3_EXTI15/LCD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); also elsewhere on the board
/GPIO_7: U14.37 (PC6/DFSDM_CKIN3/LCD_SEG24/SAI2_MCLK_A/S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); also elsewhere on the board
/GPIO_8: U14.28 (COMP1_INP/DFSDM_CKIN0/I2C3_SMBA/LPTIM1_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); also elsewhere on the board
/HPM_EN: U14.36 (ADC1_EXTI15/ADC2_EXTI15/ADC3_EXTI15/DFS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); also elsewhere on the board
/MIC_SCK: U14.41 (LCD_COM0/LPTIM2_OUT/RCC_MCO/TIM1_CH1/US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); also elsewhere on the board
/MIC_SD: U14.43 (LCD_COM2/TIM17_BKIN/TIM1_CH3/USART1_RX/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); also elsewhere on the board
/MIC_WS: U14.42 (DAC1_EXTI9/LCD_COM1/TIM15_BKIN/TIM1_CH2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); also elsewhere on the board
/PULSE1_OUT: U14.45 (CAN1_TX/TIM1_ETR/USART1_DE/USART1_RTS/U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); also elsewhere on the board
/PULSE2_OUT: U14.44 (ADC1_EXTI11/ADC2_EXTI11/ADC3_EXTI11/CAN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); also elsewhere on the board
/RE_485: U14.53 (PC12/LCD_COM6/LCD_SEG30/LCD_SEG42/SAI2_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); also elsewhere on the board
/RS232_RX: U14.16 (ADC1_IN7/ADC2_IN7/LCD_SEG1/RCC_LSCO/SAI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); also elsewhere on the board
/RS232_TX: U14.17 (ADC1_IN8/ADC2_IN8/LCD_SEG2/OPAMP1_VOUT/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); also elsewhere on the board
/STM32L4/3V3A_STM: C60.1, C61.1, L2.1, U14.13 (VDDA)
/STM32L4/8MHZ_crystal_in: C1.2, U14.5 (PH0/RCC_OSC_IN), Y1.1
/STM32L4/8MHZ_crystal_out: R26.1, U14.6 (PH1/RCC_OSC_OUT)
/STM32L4/32.768KHZ_crystal_in: C13.2, U14.3 (PC14/RCC_OSC32_IN), Y2.1
/STM32L4/32.768KHZ_crystal_out: C27.2, U14.4 (PC15/ADC1_EXTI15/ADC2_EXTI15/ADC3_EXTI1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), Y2.4
/STM32L4/ADC5: U14.26 (ADC1_IN15/ADC2_IN15/COMP1_OUT/LCD_SEG5/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); also elsewhere on the board
/STM32L4/ADC8: U14.9 (PC1/ADC1_IN2/ADC2_IN2/ADC3_IN2/DFSDM_CK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); also elsewhere on the board
/STM32L4/GPIO2: U14.39 (PC8/LCD_SEG26/SDMMC1_D0/TIM3_CH3/TIM8_C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); also elsewhere on the board
/STM32L4/GPIO4: U14.40 (PC9/DAC1_EXTI9/LCD_SEG27/SAI2_EXTCLK/SD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); also elsewhere on the board
/STM32L4/GPIO6: U14.55 (COMP2_INM/LCD_SEG7/SAI1_SCK_B/SPI1_SCK/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); also elsewhere on the board
/STM32L4/GPIO11: U14.38 (PC7/DFSDM_DATIN3/LCD_SEG25/SAI2_MCLK_B/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); also elsewhere on the board
/STM32L4/GPIO12: U14.56 (COMP2_INP/LCD_SEG8/SAI1_MCLK_B/SPI1_MIS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); also elsewhere on the board
/STM32L4/GPIO13: U14.57 (COMP2_OUT/I2C1_SMBA/LCD_SEG9/LPTIM1_IN1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); also elsewhere on the board
/STM32L4/GPIO16: U14.54 (PD2/LCD_COM7/LCD_SEG31/LCD_SEG43/SDMMC1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); also elsewhere on the board
/STM32L4/LPUART1_RX: U14.29 (COMP1_OUT/DFSDM_DATIN7/I2C2_SCL/LCD_SEG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); also elsewhere on the board
/STM32L4/LPUART1_TX: U14.30 (ADC1_EXTI11/ADC2_EXTI11/ADC3_EXTI11/COM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); also elsewhere on the board
/STM32L4/SWCLK: J5.4, U14.49 (SYS_JTCK-SWCLK/PA14)
/STM32L4/SWD_IO: J5.6, U14.46 (IR_OUT/SYS_JTMS-SWDIO/USB_OTG_FS_NOE/PA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)
/STM32L4/UART4_RX: U14.52 (PC11/ADC1_EXTI11/ADC2_EXTI11/ADC3_EXTI1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); also elsewhere on the board
/STM32L4/UART4_TX: U14.51 (PC10/LCD_COM4/LCD_SEG28/LCD_SEG40/SAI2_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); also elsewhere on the board
/STM32L4/USART1_RX: U14.59 (COMP2_INM/DFSDM_CKIN5/I2C1_SDA/LCD_SEG2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); also elsewhere on the board
/STM32L4/USART1_TX: U14.58 (COMP2_INP/DFSDM_DATIN5/I2C1_SCL/LPTIM1_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); also elsewhere on the board
/STM32L4/USART3_RX: U14.25 (PC5/ADC1_IN14/ADC2_IN14/COMP1_INP/LCD_S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); also elsewhere on the board
/STM32L4/USART3_TX: U14.24 (PC4/ADC1_IN13/ADC2_IN13/COMP1_INM/LCD_S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); also elsewhere on the board
/STM32L4/status_led: R6.1, U14.14 (ADC1_IN5/ADC2_IN5/OPAMP1_VINP/RTC_TAMP2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)
/STM_BOOT0: R15.2, R16.2, U14.60 (BOOT0); also elsewhere on the board
/STM_MISO: U14.22 (ADC1_IN11/ADC2_IN11/LCD_SEG3/OPAMP2_VIN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); also elsewhere on the board
/STM_MOSI: U14.23 (ADC1_IN12/ADC2_IN12/LCD_SEG4/OPAMP2_VIN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); also elsewhere on the board
/STM_NRST: C62.1, J5.5, R119.2, S1.2, U14.7 (NRST); also elsewhere on the board
/STM_SCK: U14.21 (ADC1_IN10/ADC2_IN10/DAC1_OUT2/LPTIM2_ET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); also elsewhere on the board
/STM_SCL: U14.61 (CAN1_RX/DFSDM_DATIN6/I2C1_SCL/LCD_SEG16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); also elsewhere on the board
/STM_SDA: U14.62 (CAN1_TX/DAC1_EXTI9/DFSDM_CKIN6/I2C1_SDA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); also elsewhere on the board
/STM_WAKEUP: U14.2 (PC13/RTC_OUT_ALARM/RTC_OUT_CALIB/RTC_TA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); also elsewhere on the board
unnamed: C12.2, R26.2, Y1.3
unnamed: D8.1 (K), R6.2
unnamed: R30.1, S1.3
unnamed: R37.1, U14.1 (VBAT)

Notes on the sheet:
SWD Programming Header
Note: For comfirmation of pin functions refer to datasheet. Symbol may not be correct - wkup pins 2,14,16,25 -pa13, pa15, pb4 avoid as after reset internal pull up and pull down activated
I=vs-vf/R 3.3-2/1.3k=1mA

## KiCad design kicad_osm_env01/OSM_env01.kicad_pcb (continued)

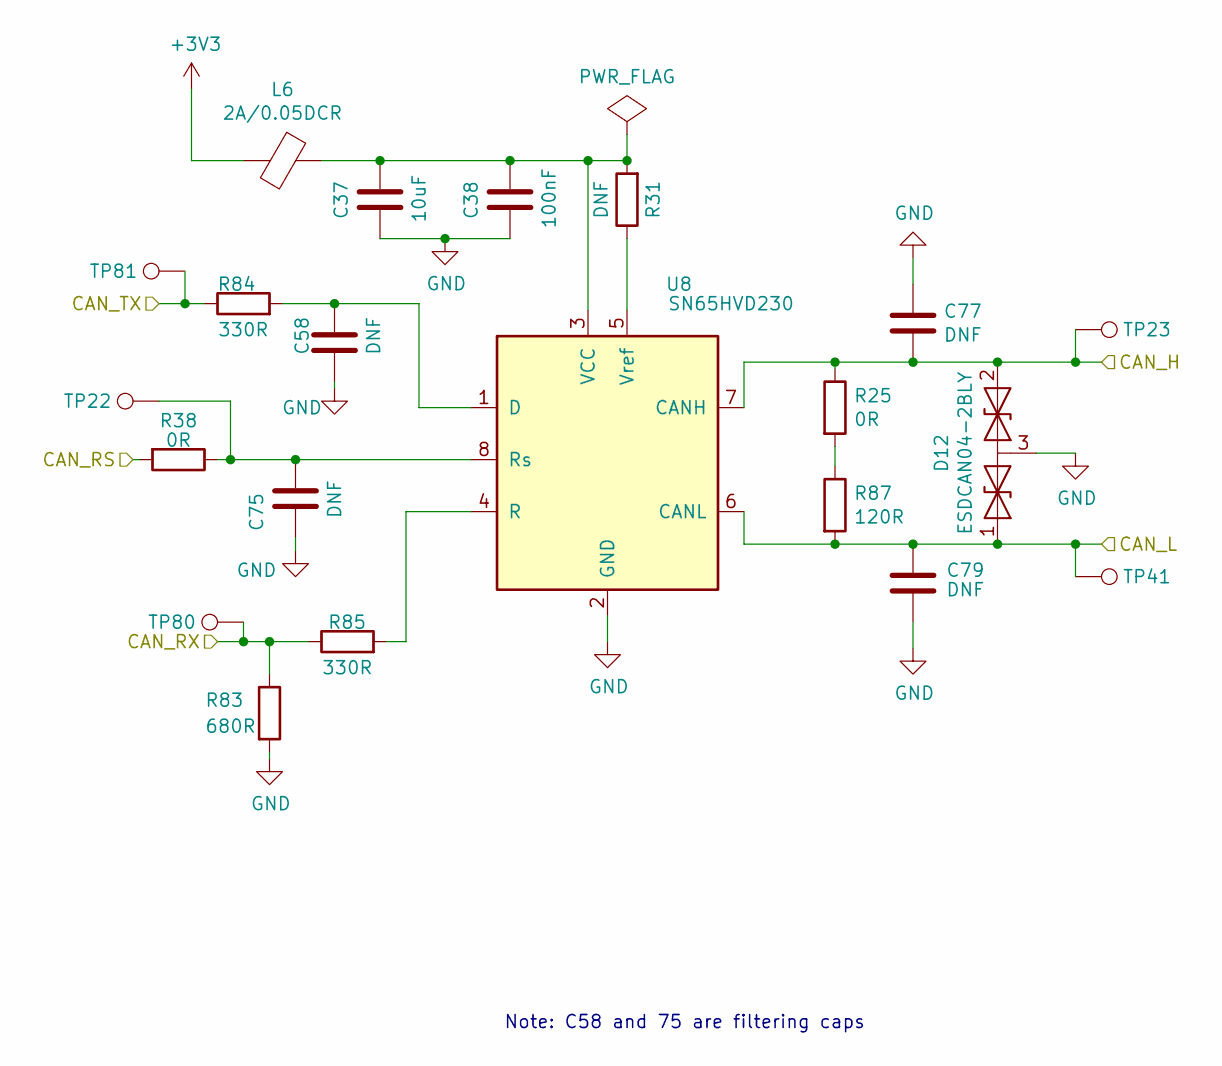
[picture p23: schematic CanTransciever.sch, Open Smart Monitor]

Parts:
C37: 10uF; C_0603_1608Metric
C38: 100nF; C_0402_1005Metric
C58, C75, C77, C79: DNF; C_0603_1608Metric
D12: ESDCAN04-2BLY; SOT-23
L6: 2A/0.05DCR; L_0402_1005Metric
R25, R38: 0R; R_0603_1608Metric
R31: DNF; R_0603_1608Metric
R83: 680R; R_0603_1608Metric
R84, R85: 330R; R_0603_1608Metric
R87: 120R; R_0603_1608Metric
TP22, TP23, TP41, TP80, TP81: Test_Point; TestPoint_Pad_D1.5mm
U8: SN65HVD230; SOIC-8_3.9x4.9mm_P1.27mm

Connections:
/CAN_H: C77.2, D12.2 (A2), R25.1, TP23.1, U8.7 (CANH); also elsewhere on the board
/CAN_L: C79.2, D12.1 (A1), R87.2, TP41.1, U8.6 (CANL); also elsewhere on the board
/CAN_RS: R38.2; also elsewhere on the board
/CAN_RX: R83.1, R85.1, TP80.1; also elsewhere on the board
/CAN_TX: R84.1, TP81.1; also elsewhere on the board
unnamed: C37.2, C38.2, L6.1, R31.2, U8.3 (VCC)
unnamed: C58.1, R84.2, U8.1 (D)
unnamed: C75.2, R38.1, TP22.1, U8.8 (Rs)
unnamed: R25.2, R87.1
unnamed: R31.1, U8.5 (Vref)
unnamed: R85.2, U8.4 (R)

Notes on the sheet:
Note: C58 and 75 are filtering caps

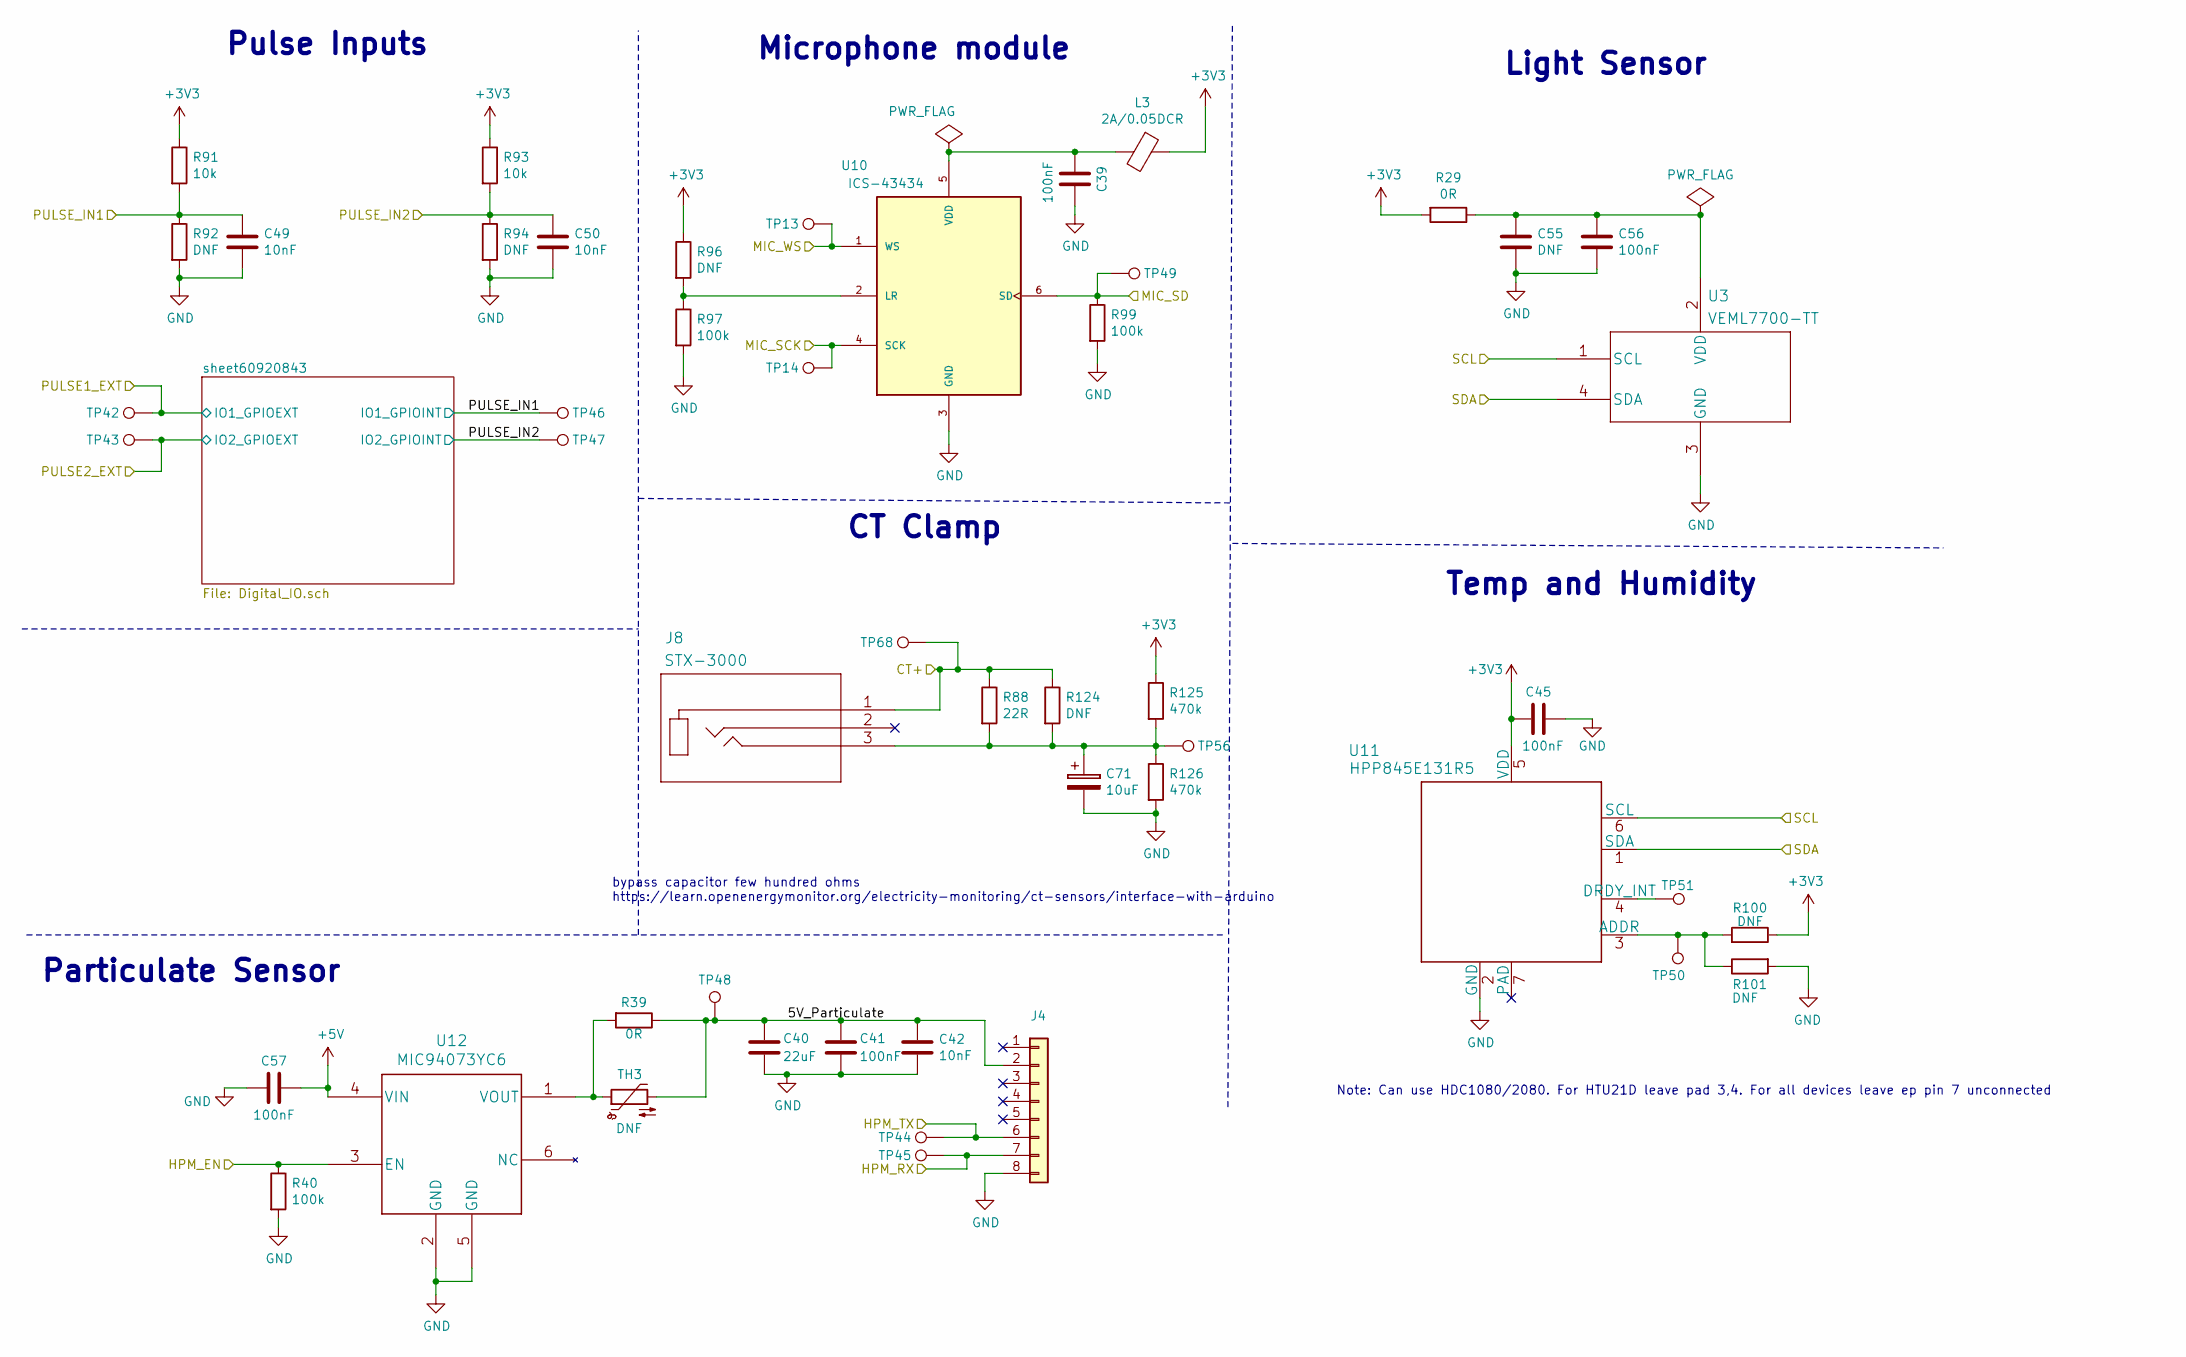
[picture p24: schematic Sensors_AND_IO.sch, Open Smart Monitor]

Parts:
C39, C41, C45, C56, C57: 100nF; C_0402_1005Metric
C40: 22uF; C_0805_2012Metric
C42, C49, C50: 10nF; C_0402_1005Metric
C55: DNF; C_0603_1608Metric
C71: 10uF; CP_Elec_4x5.4
J4: Conn_01x08; Molex_PicoBlade_53047-0810_1x08_P1.25mm_Vertical
J8: STX-3000
L3: 2A/0.05DCR; L_0402_1005Metric
R29, R39: 0R; R_0603_1608Metric
R40, R97, R99: 100k; R_0603_1608Metric
R88: 22R; R_1206_3216Metric
R91, R93: 10k; R_0603_1608Metric
R92, R94, R96, R100, R101: DNF; R_0603_1608Metric
R124: DNF; R_1206_3216Metric
R125, R126: 470k; R_0603_1608Metric
TH3: DNF; R_Axial_DIN0617_L17.0mm_D6.0mm_P5.08mm_Vertical
TP13, TP14, TP48, TP49: Test_Point; TestPoint_THTPad_D1.0mm_Drill0.5mm
TP42, TP43, TP44, TP45, TP46, TP47, TP50, TP51, TP56, TP68: Test_Point; TestPoint_Pad_D1.5mm
U3: VEML7700-TT
U10: ICS-43434
U11: HPP845E131R5; HPP845E131R5_temperature_humidity_sensor
U12: MIC94073YC6; SOT-363_SC-70-6

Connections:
+5V: C57.2, U12.4 (VIN); also elsewhere on the board
/CT+: J8.1, R88.1, R124.1, TP68.1; also elsewhere on the board
/HPM_EN: R40.1, U12.3 (EN); also elsewhere on the board
/HPM_RX: J4.7, TP45.1; also elsewhere on the board
/HPM_TX: J4.6, TP44.1; also elsewhere on the board
/MIC_SCK: TP14.1, U10.4 (SCK); also elsewhere on the board
/MIC_SD: R99.1, TP49.1, U10.6 (SD); also elsewhere on the board
/MIC_WS: TP13.1, U10.1 (WS); also elsewhere on the board
/PULSE1_EXT: TP42.1; also elsewhere on the board
/PULSE1_OUT: C49.1, R91.2, R92.1, TP46.1; also elsewhere on the board
/PULSE2_EXT: TP43.1; also elsewhere on the board
/PULSE2_OUT: C50.1, R93.2, R94.1, TP47.1; also elsewhere on the board
/STM_SCL: U3.1 (SCL), U11.6 (SCL); also elsewhere on the board
/STM_SDA: U3.4 (SDA), U11.1 (SDA); also elsewhere on the board
/Sensors_AND_IO/5V_Particulate: C40.1, C41.1, C42.1, J4.2, R39.1, TH3.2, TP48.1
unnamed: C39.2, L3.2, U10.5 (VDD)
unnamed: C55.1, C56.1, R29.1, U3.2 (VDD)
unnamed: C71.1, J8.3, R88.2, R124.2, R125.2, R126.1, TP56.1
unnamed: R39.2, TH3.1, U12.1 (VOUT)
unnamed: R96.2, R97.1, U10.2 (LR)
unnamed: R100.2, R101.1, TP50.1, U11.3 (ADDR)
unnamed: TP51.1, U11.4 (DRDY_INT)

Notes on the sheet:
Temp and Humidity
Particulate Sensor
Microphone module
CT Clamp
bypass capacitor few hundred ohms https://learn.openenergymonitor.org/electricity-monitoring/ct-sensors/interface-with-arduino
Note: Can use HDC1080/2080. For HTU21D leave pad 3,4. For all devices leave ep pin 7 unconnected
Light Sensor
Pulse Inputs

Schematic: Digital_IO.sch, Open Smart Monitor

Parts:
D14, D16: BAV99; SOT-23
R104, R105: 1k; R_0603_1608Metric

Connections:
/PULSE1_EXT: R104.2; also elsewhere on the board
/PULSE1_OUT: D14.3 (K), R104.1; also elsewhere on the board
/PULSE2_EXT: R105.2; also elsewhere on the board
/PULSE2_OUT: R105.1; also elsewhere on the board

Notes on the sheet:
3V3 BI-DIRECTIONAL IO (5V TOLERANT)
Max 3mA per GPIO

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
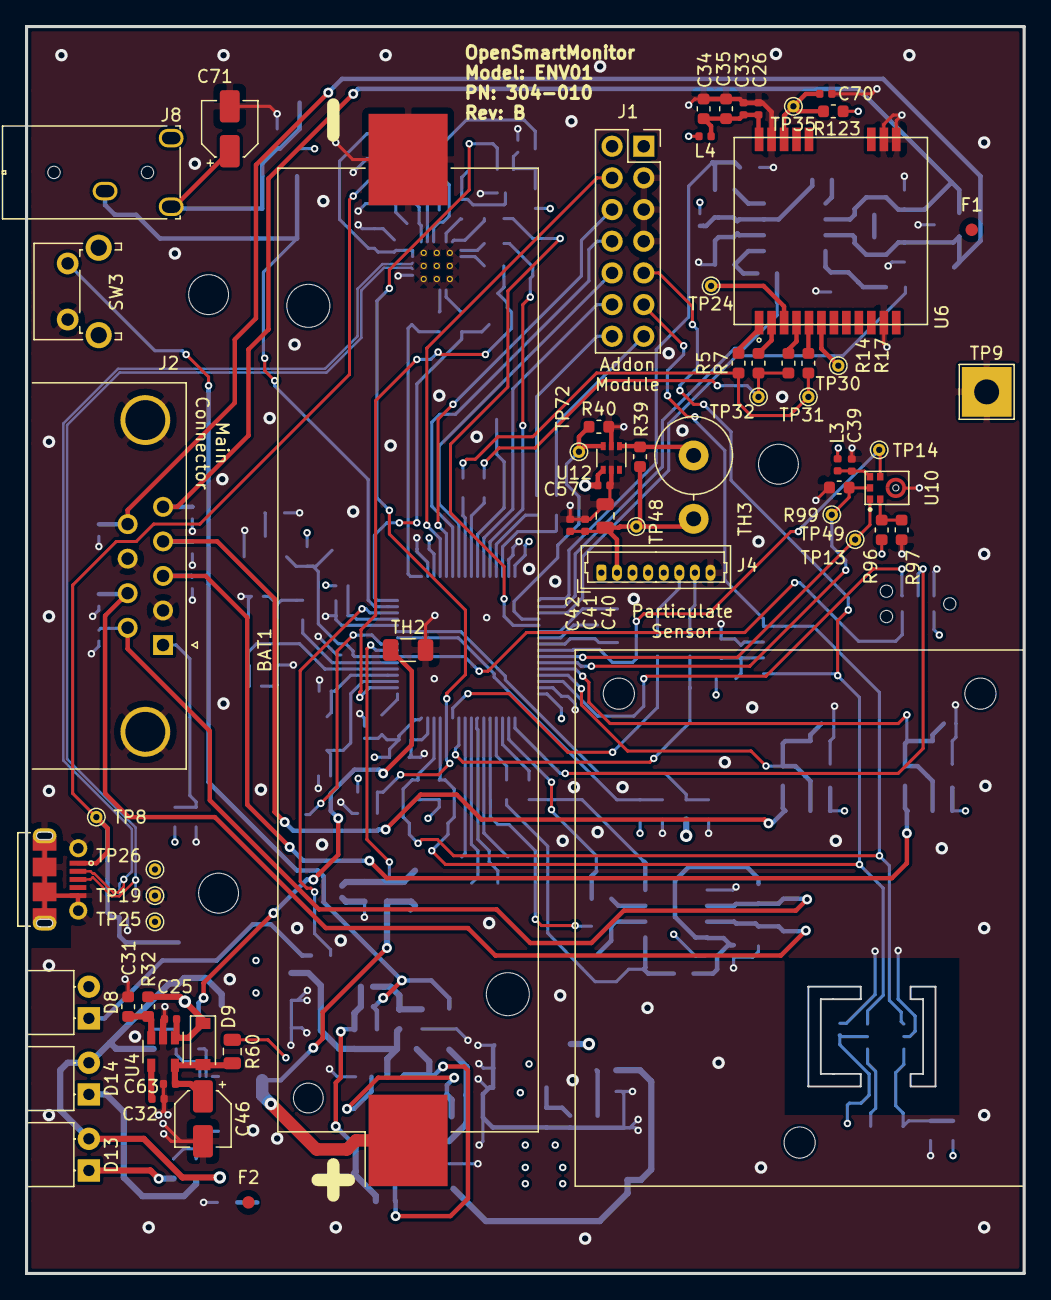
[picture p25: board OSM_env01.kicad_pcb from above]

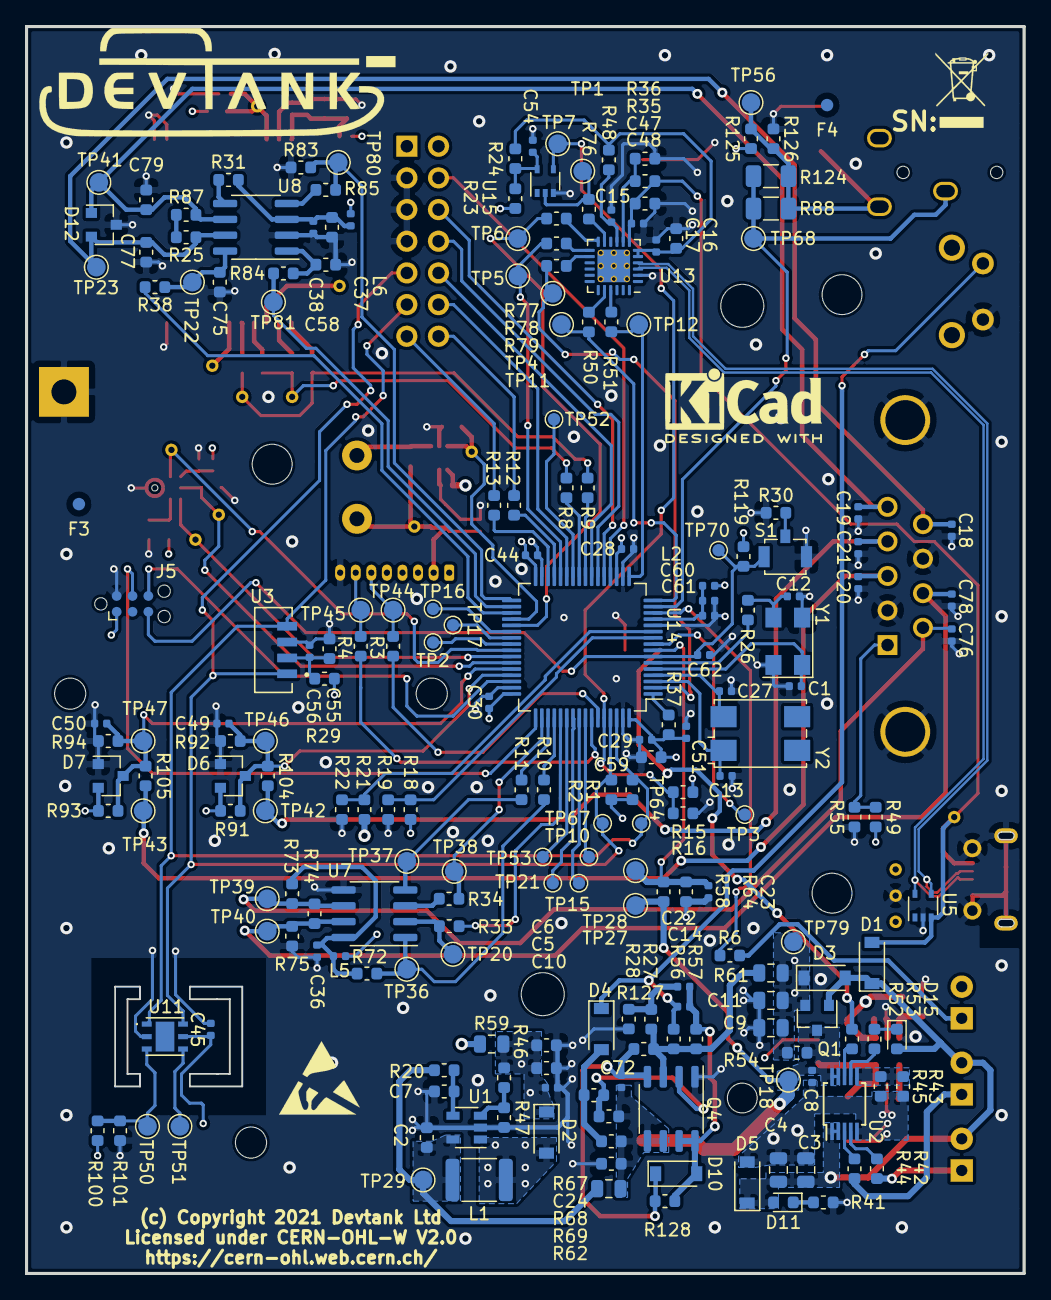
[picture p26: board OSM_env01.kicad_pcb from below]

Board: 4 copper layers, 80.0 x 100.0 mm, 279 parts (215 on the bottom side), 144 nets.

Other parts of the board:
D6, D7: BAV99; SOT-23

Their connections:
/PULSE1_OUT: D6.3; also elsewhere on the board
/PULSE2_OUT: D7.3; also elsewhere on the board

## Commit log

2021-03-19 setup main public project with clean history
    [DigitalIO.sch, Digital_IO.sch, OSM_env01.kicad_pcb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]
2021-03-19 updated CERN license
    [OSM_env01.kicad_pcb]
2021-03-19 added BOM
    [OSM_ENV01_BOM_RevA.ods]
2021-03-23 audio circuit updated
    [OSM_env01.sch, Sound.sch]
2021-03-26 pushed latest schematics got started with micro into schematic
    [Digital_IO.sch, LORA.sch, OSM_env01.sch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]
2021-03-30 stm32 added to kicad
    [Digital_IO.sch, ESP.sch, LORA.sch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]
2021-03-30 kicad review sch initial
    [LORA.sch, OSM_env01.sch, PowerSupply.sch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]
2021-03-31 updated schematics
    [CanTransciever.sch, Digital_IO.sch, LORA.sch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]
2021-04-06 schematics awaiting review
    [CanTransciever.sch, Digital_IO.sch, LORA.sch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]
2021-04-08 started layout
    [CanTransciever.sch, Digital_IO.sch, LORA.sch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]
2021-04-09 Throwdown of parts
    [CanTransciever.sch, LORA.sch, OSM_env01.kicad_pcb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]
2021-08-26 updated 3d step file
    [CanTransciever.sch, LORA.sch, OSM_env01.csv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]
2021-09-07 added stm to schematic
    [OSM_env01.kicad_pcb, OSM_env01.sch, STM32L4.sch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]
2021-09-12 pushed common folder with schematics
2021-09-15 rough layout with throwdown of parts
    [CanTransciever.sch, Digital_IO.sch, LORA.sch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]
2021-09-21 added caps to particulate sensor
    [Sensors_AND_IO.sch]
2021-09-23 rough throwdown of all parts
    [CanTransciever.sch, Digital_IO.sch, LORA.sch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]
2021-09-27 schematics and layout submitted for review
    [OSM_env01.kicad_pcb, OSM_env01.sch, PowerSupply.sch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]
2021-09-29 osm env-01 revB finished
    [CanTransciever.sch, Digital_IO.sch, LORA.sch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]
2021-09-30 Bom and gerbers added
    [LORA.sch, OSM_ENV01_BOM_REVB.ods, OSM_ENV01_BOM_REVB_wcost.ods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]
2021-09-30 added part numbers to bom
    [OSM_ENV01_BOM_REVB.ods, OSM_ENV01_BOM_REVB_wcost.ods]
2021-10-20 Remove absolute pathes, replace with relative paths.
    [OSM_env01.kicad_pcb]

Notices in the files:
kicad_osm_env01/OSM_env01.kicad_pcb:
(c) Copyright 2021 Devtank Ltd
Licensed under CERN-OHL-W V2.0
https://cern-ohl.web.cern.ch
